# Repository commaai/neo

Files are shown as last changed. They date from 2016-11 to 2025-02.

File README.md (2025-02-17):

neo
=====

<b>NOTE: The NEO is deprecated. Check out the [latest hardware](https://github.com/commaai/hardware).

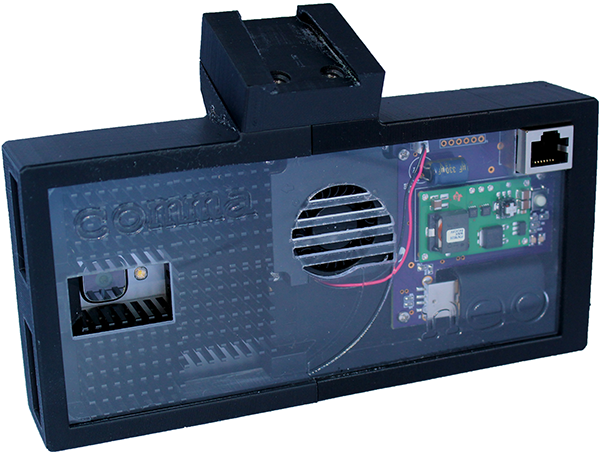
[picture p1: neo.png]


The neo is an open source robotics research platform. It is powered by a OnePlus 3 smartphone and an [STM32F205](http://www.st.com/en/microcontrollers/stm32f2x5.html?querycriteria=productId=LN1433)-based CAN interface board, in a 3d-printed housing with active cooling.

The neo platform includes [NEOS](https://github.com/commaai/eon-neos), a stripped down Android ROM designed for robustness and to get out of the way of your software. It also provides a modern linux environment for easy development.

Why
------

You cannot get a higher performance embedded processor than what's shipping in modern smartphones. They also come with an impressive array of sensors and radios, and are very low cost.

For some background see the work of [Android Based Robots](http://www.socsci.uci.edu/~jkrichma/ABR/abr_background.html).

Build
------

The neo is designed to be very easy to construct. You need to be able to shop online and use a soldering iron.

There is a **[very detailed guide](https://github.com/commaai/neo/raw/master/guide.pdf)** with instructions on what to order and how to build a neo.

to build a neo, 6 orders must be placed from the following sources:
- digikey
- mcmaster
- shapeways
- oshpark
- amazon
- oneplus

The total cost is about $700.

Directory structure
------

- board -- EagleCAD schematic, board, and library files
- parts -- csv bill of materials
- case -- stl files for 3d printing

Licensing
------

neo research platform is released under the MIT license.

**THIS IS ALPHA QUALITY SOFTWARE FOR RESEARCH PURPOSES ONLY. THIS IS NOT A PRODUCT.
YOU ARE RESPONSIBLE FOR COMPLYING WITH LOCAL LAWS AND REGULATIONS.
NO WARRANTY EXPRESSED OR IMPLIED.**

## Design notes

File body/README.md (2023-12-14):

Body
=====

Stands
------

For wheeled stands you can use any office chair wheels but we recommend: <a href="https://www.amazon.com/gp/product/B088D8XHHQ/ref=ppx_yo_dt_b_search_asin_title?ie=UTF8&psc=1">these</a>
They are press-fit so you will need to apply some amount of force (or use wise)

Hat (for C3/C3X)
------

After you print a hat and a hat frame you will also need <a href="https://www.mcmaster.com/93070A107/">4pcs M4x20 screws</a> and <a href="https://www.amazon.com/gp/product/B07T5L7756/ref=ppx_yo_dt_b_search_asin_title?ie=UTF8&th=1">EVA foam</a> to protect the screen of your device. Cut two 9mm x 70mm stripes and apply them to inside of the hat frame.

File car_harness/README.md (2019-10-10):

car harness
===

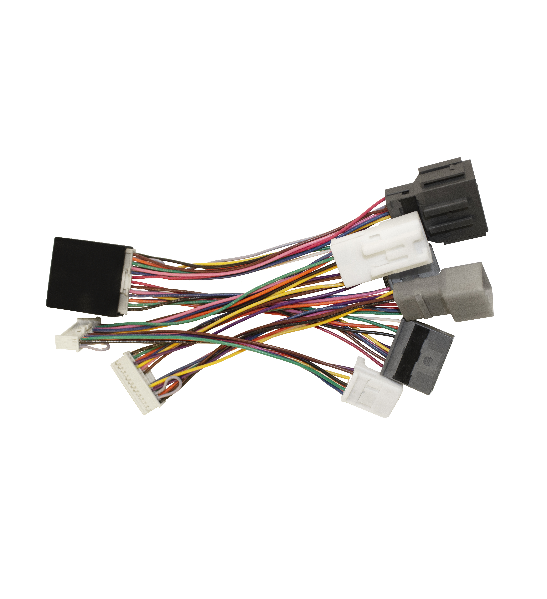
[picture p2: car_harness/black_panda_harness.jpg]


This is the documentation for the 26 pin connector on the car harness.

The car harness currently supports Honda Nidec, Honda Bosch, and Toyota. We would like to support more cars in the future.

Pull requests for additional pin outs are welcome. Please reference the open_pinout.sch.pdf file for adding new cars. This will guarantee the harness will work properly.

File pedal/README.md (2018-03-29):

pedal
=====

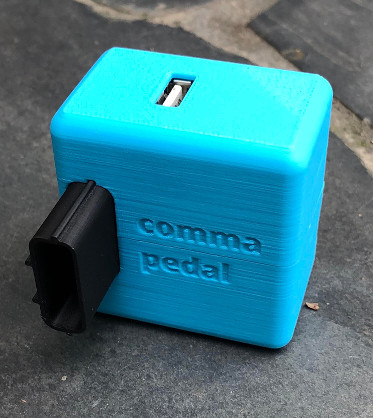
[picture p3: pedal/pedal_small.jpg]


This is the open source hardware for the comma pedal. It borrows from the NEO board.

Open source firmware available at https://github.com/commaai/panda/tree/master/board/pedal

The comma pedal is a gas pedal interceptor for Honda/Acura. It allows you to "virtually" press the pedal, enabling stop and go cruise control on select cars.

Licensing
------

Released under the MIT license.

**THIS IS ALPHA QUALITY HARDWARE FOR RESEARCH PURPOSES ONLY. THIS IS NOT A PRODUCT.
YOU ARE RESPONSIBLE FOR COMPLYING WITH LOCAL LAWS AND REGULATIONS.
NO WARRANTY EXPRESSED OR IMPLIED.**

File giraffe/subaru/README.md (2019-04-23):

Subaru giraffe
====

Get your panda deeper into your Subaru Impreza
May work with other cars with the same connector

====

All switching between stock ADAS on and Stock ADAS off is done via a relay

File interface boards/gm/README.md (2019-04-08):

GM Interface Board

====

Design from the community from: [@vntarasov](https://github.com/vntarasov)

**THIS IS ALPHA QUALITY HARDWARE, NOT TESTED, NOR DESIGNED BY COMMA.AI, FOR RESEARCH PURPOSES ONLY. THIS IS NOT A PRODUCT.
YOU ARE RESPONSIBLE FOR COMPLYING WITH LOCAL LAWS AND REGULATIONS.
NO WARRANTY EXPRESSED OR IMPLIED.**

=====

Parts for case assembly (mcmaster part numbers):
- 92010A122, M3 12mm flat head
- 94180A331, M3 heat insert

PCB parts: digikey.csv

Connector pins:
- For data pins, Digikey part # SAM12735-ND
- For power & ground pins, Mouser part # 829-15304702

Assembly steps:
- Order PCB from Oshpark and populate yourself, or order a populated PCB from Macrofab
  Solder everything except for connector headers and power pins
- Flash the board with
  - Connect 5v, ground, data+, data- to USB host. Use external 5v power
  - Don't use 5v linear regulator for USB power, it will get fried
  - Pull high (to +3.3v net) BOOT testpoint, through 1k resistor, to put board into DFU
- Print case.stl and connector.stl, use ABS filament
- Install m3 heat insert into the case
- Drill holes in the connector housing for easier insertion of data pins, from 0.7mm to 0.75mm
- Cut 0.1" connector header SAM12735-ND to 12-pin and 16-pin sizes
- Cut one of the 829-15304702 short, bend the other one 90 degrees
- Insert shorter 829-15304702 (+12v) into connector housing
  - Put enough solder on the +12v testpoint of the PCB
  - Insert 0.1" headers into PCB, then solder the +12v pin to the PCB
  - Connector's plastic is going to melt, immobilizing the +12v pin is recommended
- Solder 0.1" headers to the PCB
- Insert 90-degrees bent 829-15304702 (ground) into connector housing, solder to PCB
- Bolt down connector housing to the case

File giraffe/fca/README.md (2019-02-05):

FCA (Fiat Chrysler Automotive) Giraffe
====

Get your panda deeper into your:

- 2017 Chrysler Pacifica Hybrid

May fit other FCA cars as well.

The switches
====

The 2 DIP switches control signals to the stock ADAS system

- 1 -- IGN to camera

- 2 -- ADAS CAN1 -> camera CAN (OBDII pins 12 & 13)

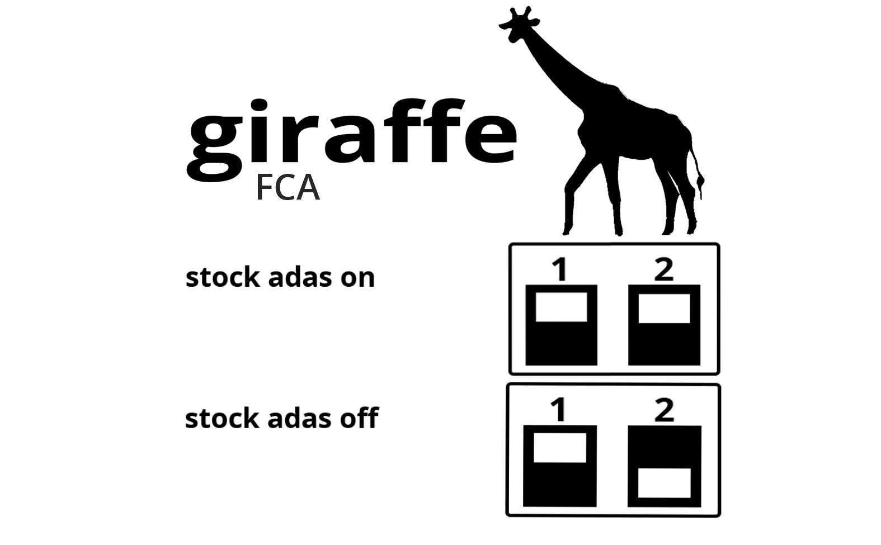
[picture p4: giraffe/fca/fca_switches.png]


Initial design from the community from: [@adhintz](https://github.com/adhintz)

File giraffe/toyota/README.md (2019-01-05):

Toyota giraffe
====

Get your panda deeper into your compatible Toyota vehicle

The switches
====

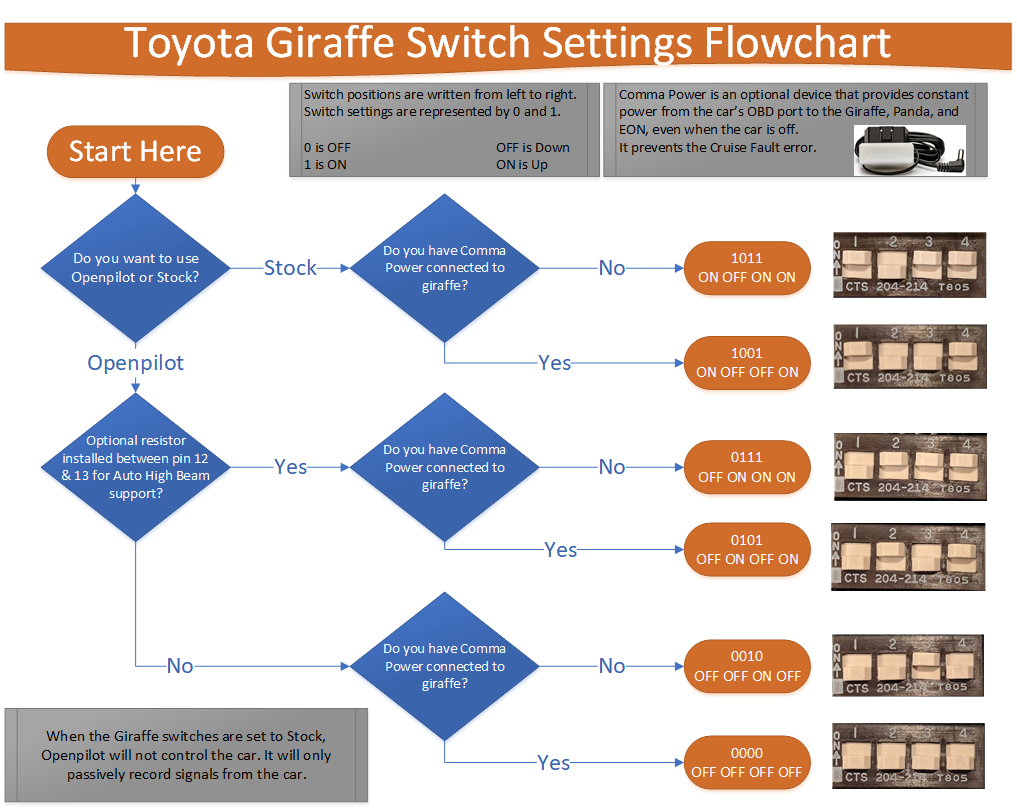
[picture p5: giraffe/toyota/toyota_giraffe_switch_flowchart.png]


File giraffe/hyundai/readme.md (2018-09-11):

Hyundai giraffe
====

Get your panda deeper into your compatible Hyundai vehicle. Built with pinout for our Hyundai Sante Fe. May work with other Hyundai/Kia, check EWD for verification. 

The switches
====

The 4 DIP switches control signals to the stock ADAS system

- 1 -- ADAS CAN1 -> main body CAN

- 2 -- ADAS CAN1 -> panda CAN3 (OBDII pins 12 & 13)

- 3 -- IGNITION POWER -> panda power

- 4 -- ADAS power & ignition -> power & ignition

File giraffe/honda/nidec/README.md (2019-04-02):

Honda giraffe
====

Get your panda deeper into your Honda Civic or Acura ILX

The switches
====

The 4 DIP switches control signals to the stock ADAS system

- 1 -- ADAS CAN1 -> main body CAN

- 2 -- ADAS CAN1 -> panda CAN3 (OBDII pins 12 & 13)

- 3 -- ADAS CAN2 -> radar CAN

- 4 -- ADAS power & ignition -> power & ignition

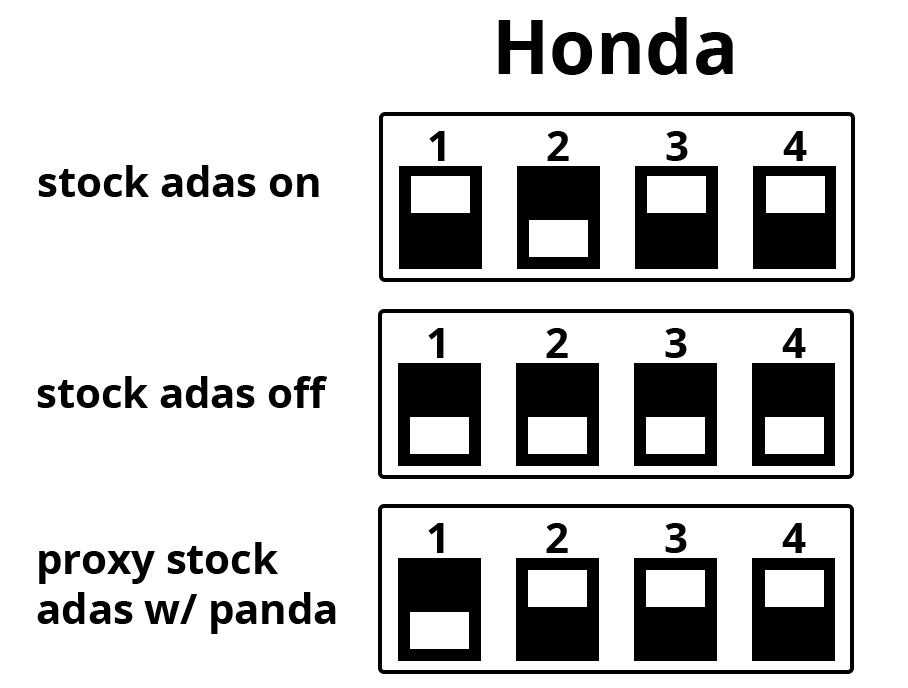
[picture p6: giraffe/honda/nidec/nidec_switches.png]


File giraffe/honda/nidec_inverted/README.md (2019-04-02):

Honda Inverted Giraffe
====

Get your panda deeper into your Odyssey, 2019 Honda Pilot, TLX and probably other cars with an "inverted" connector

The switches
====

The 4 DIP switches control signals to the stock ADAS system

- 1 -- ADAS CAN1 -> main body CAN

- 2 -- ADAS CAN1 -> panda CAN3 (OBDII pins 12 & 13)

- 3 -- ADAS CAN2 -> radar CAN

- 4 -- ADAS power & ignition -> power & ignition



Thanks to [@csouers](https://github.com/csouers) and [@energee](https://github.com/energee) for their input on this design

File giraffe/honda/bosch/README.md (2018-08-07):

Honda giraffe (Bosch ADAS)
====

Get your panda deeper into your:

- 2017+ Honda CR-V
- 2017+ Honda Civic Hatchback
- 2018+ Honda Accord

May fit other Hondas with Bosch hardware as well.

The switches
====

The 2 DIP switches control signals to the stock ADAS system

- 1 -- IGN to camera

- 2 -- ADAS CAN2 -> camera CAN (OBDII pins 12 & 13)

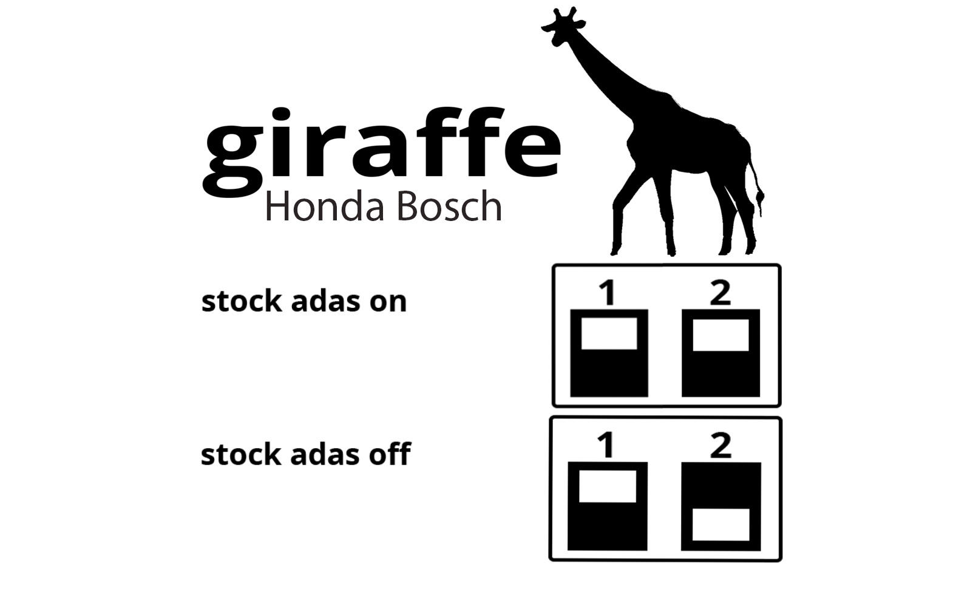
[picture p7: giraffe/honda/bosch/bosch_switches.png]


Initial design from the community from: [@csouers](https://github.com/csouers), [@energee](https://github.com/energee), and Alaric Egli

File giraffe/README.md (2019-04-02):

giraffe
====

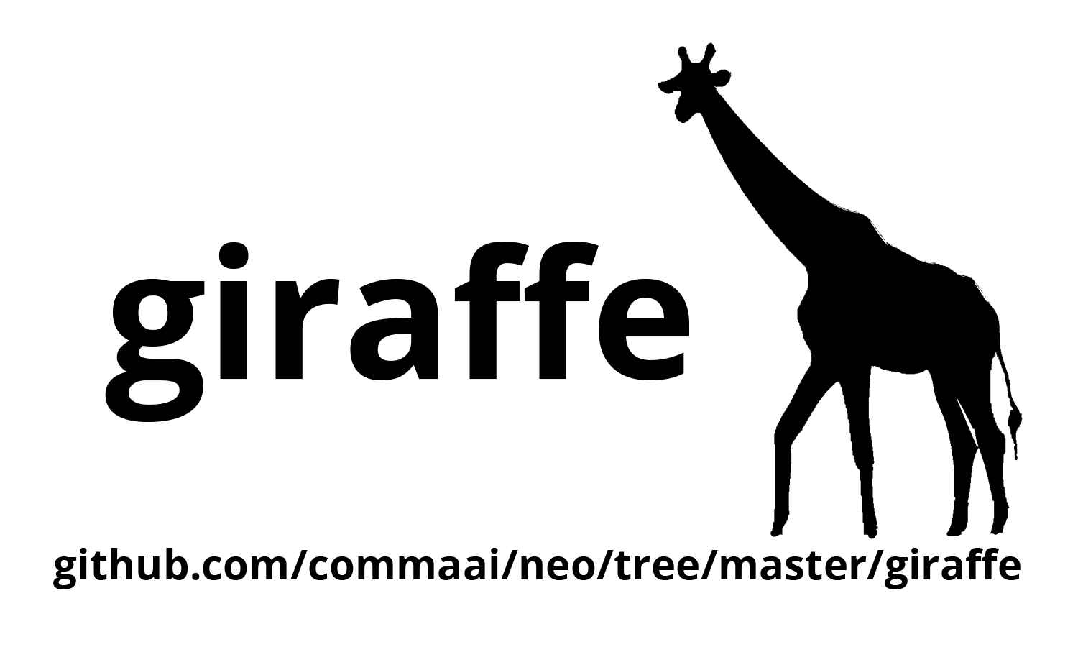
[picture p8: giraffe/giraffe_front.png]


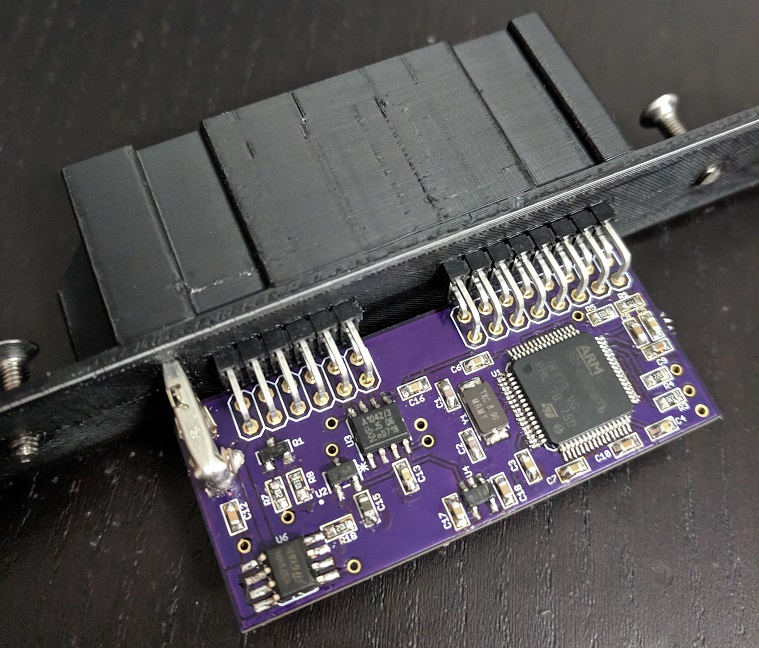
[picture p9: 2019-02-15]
interface boards/gm/resources/1) front.jpg

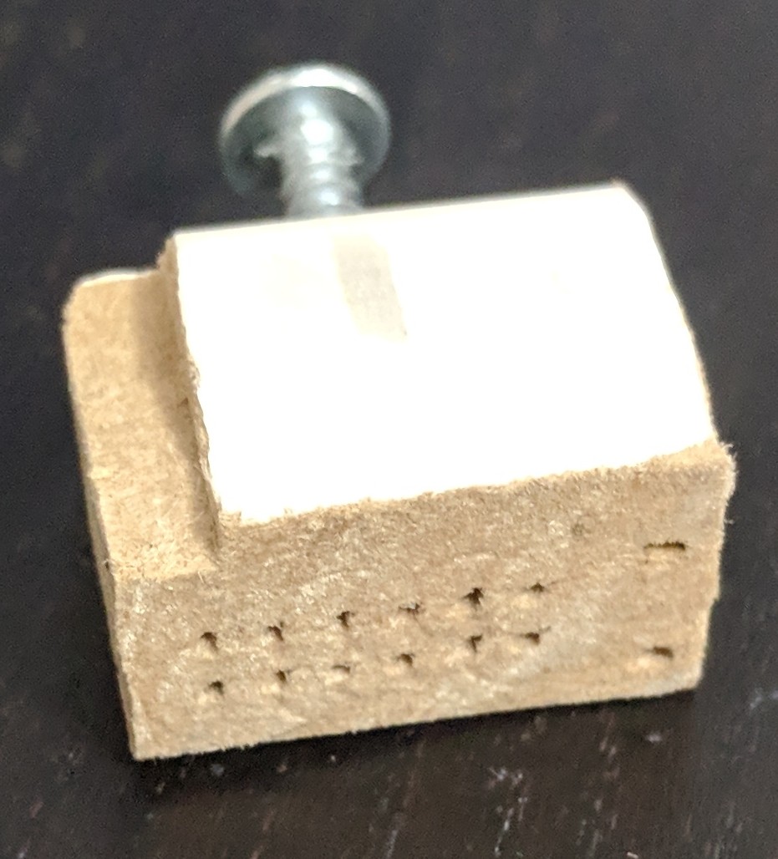
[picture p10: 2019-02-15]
interface boards/gm/resources/4) pin immobilizer.jpg

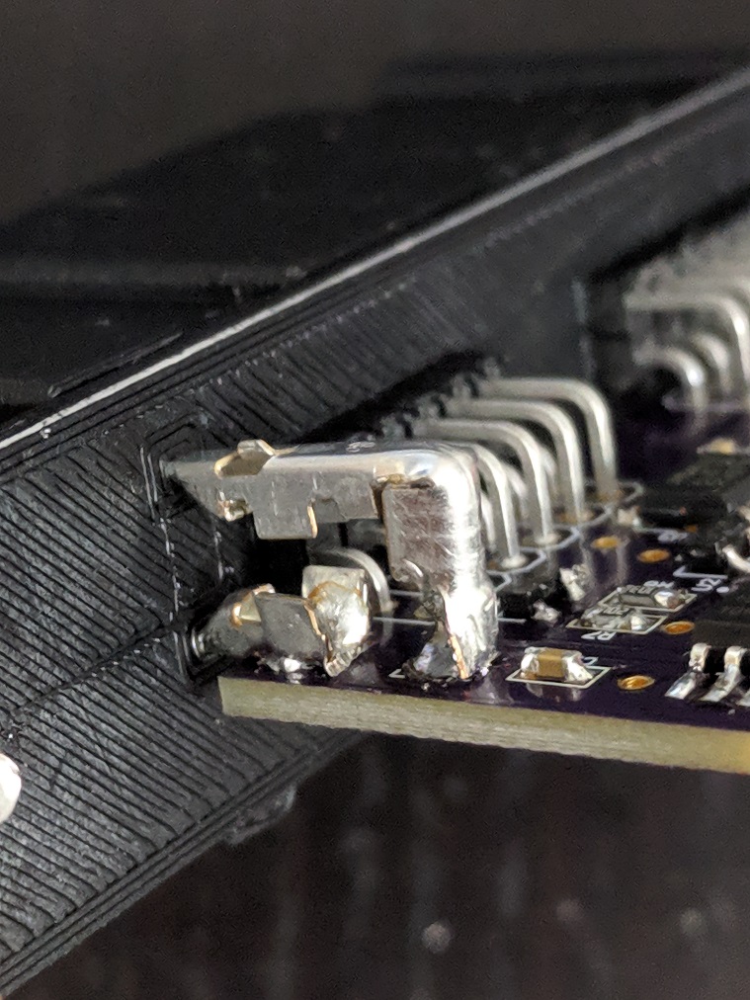
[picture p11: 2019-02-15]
interface boards/gm/resources/2) power pins.jpg

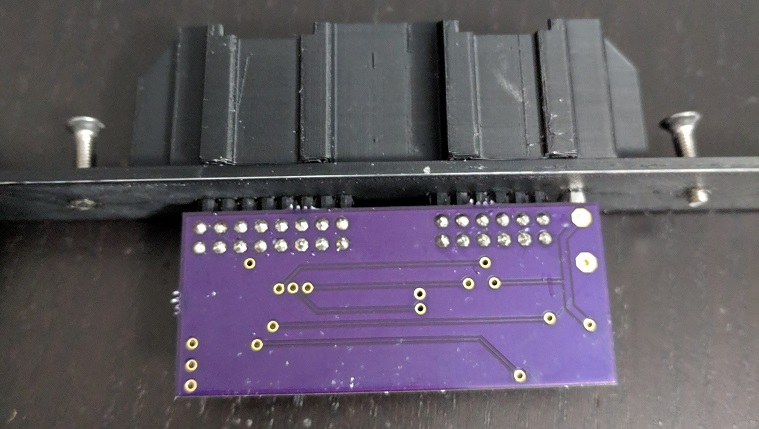
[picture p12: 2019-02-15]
interface boards/gm/resources/3) back.jpg

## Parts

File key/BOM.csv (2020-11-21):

Part | Value | Device | Package | Description | DESIGNER | MPN | POPULARITY | VERSION
DFU | SPST-2-4PIN | SPST-2-4PIN | EVQ-Q2 |  |  | EVQ-Q2Y03W
J1 | USB-C | USB-C | USB-C |  |  | 10544440001
J2 | USB-C-FEMALE | USB-C-FEMALE | DX07S024XJ1R1100 |  |  | DX07S024XJ1R1100
SHIELD |  | 1,6/0,8 | 1,6/0,8 | THROUGH-HOLE PAD |  |  | 15
SW2 | DPDTDPDT | DPDTDPDT | AYZ0202 |  |  | JS202011SCQN

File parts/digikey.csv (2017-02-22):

digikey part num | order qty | qty used | ref des | value | footprint
1276-1817-1-ND | 3 | 2 | C1, C2 | 8pF | 0603
490-1532-1-ND | 10 | 9 | C3, C4, C5, C6, C7, C11, C13, C16, C17 | 100nF | 0603
490-3296-1-ND | 4 | 3 | C9, C10, C18 | 2.2uF | 0603
490-10744-1-ND | 3 | 2 | C12, C15 | 2.2uF | 0805
P12372-ND | 1 | 1 | C14 | 330uF | radial
1276-1784-1-ND | 2 | 1 | C8 | 4.7uF | 0603
S1011EC-40-ND | 1 | 1 | J1 | uart connector | thru hole-6
WM1731-ND | 1 | 1 | J2 | fan connector | thru hole-2
WM17118-ND | 1 | 1 | J3 | usb a | smd-4
AE10398-ND | 1 | 1 | J4 | rj45 | thru hole-8
670-2294-ND | 1 | 1 | J5 | jae 20 pin | thru hole-20
475-1410-1-ND | 2 | 1 | LED1 | green | 0805
475-1415-1-ND | 2 | 1 | LED2 | red | 0805
MMBT2222ALT1GOSCT-ND | 2 | 1 | Q1 | mmbt2222a | sot23-3
311-10KGRCT-ND | 10 | 6 | R1, R5, R8, R12, R14, R15 | 10k | 0603
311-18.7KHRCT-ND | 10 | 1 | R11 | 18.7k | 0603
311-1.0KGRCT-ND | 10 | 2 | R6, R7 | 1k | 0603
311-2.7KGRCT-ND | 10 | 2 | R2, R13 | 2.7k | 0603
311-22GRCT-ND | 10 | 2 | R3, R4 | 22 | 0603
311-220GRCT-ND | 10 | 2 | R9, R10 | 220 | 0603
P12961SCT-ND | 1 | 1 | SW1 | spst | smd-4
497-11153-ND | 1 | 1 | U1 | stm32f205 | lqfp-64
296-20515-ND | 1 | 1 | U2 | ptn78020w | thru hole-7
568-8681-1-ND | 1 | 1 | U3 | tja1048 | so14
296-36844-1-ND | 2 | 1 | U4 | 3.3v | sot23-5
887-1667-1-ND | 2 | 1 | Y1 | 8MHz | smd-2
603-1840-ND | 1 | 1 | H1 | 12V fan | 40x10mm
345-1102-ND | 4 | 4 | H2, H3, H4, H5 | heatsink | 28mm

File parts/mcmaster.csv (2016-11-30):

mcmaster part num | pack qty | qty used | ref des | description
92010A005 | 1 | 1 | A | m2 10mm flat head
92010A122 | 1 | 4 | B | m3 12mm flat head
92000A013 | 1 | 7 | C | m2 6mm pan head
91828A111 | 1 | 6 | D | m2 hex nut
94180A331 | 1 | 4 | E | m3 heat set insert
94180A307 | 1 | 2 | F | m2 heat set insert

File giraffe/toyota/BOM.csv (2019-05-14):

Ref Des | Package | Manufacturer PN | Qty | Link
J1 | 12-pin | 1318774-1 | 1 | http://www.mouser.com/Search/ProductDetail.aspx?R=1318774-1virtualkey57100000virtualkey571-1318774-1
J2 | 12-pin-RA | 1318772-2 | 1 | http://www.mouser.com/Search/ProductDetail.aspx?R=1318772-2virtualkey57100000virtualkey571-1318772-2
 |  | 1123343-1 | 12 | https://www.digikey.com/product-detail/en/te-connectivity-amp-connectors/1123343-1/A107011CT-ND/3488572
 |  | PRPC040SAAN-RC | 1 | https://www.digikey.com/products/en?keywords=S1011EC-40-ND
J3 | 16-pin | OBDII-FEMALE | 1 | https://cn1514770021qfbj.en.alibaba.com/product/60598699808-804284542/J1962F_OBD2_16_Pin_Female_connector_OBD2_Socket.html
J4 | RJ45-RA | A-2004-2-4-LPS-N-R | 1 | https://www.digikey.com/product-detail/en/assmann-wsw-components/A-2004-2-4-LPS-N-R/AE10387-ND/2183638
J5 | 3-pin | EJ508A | 1 | https://www.digikey.com/products/en?keywords=ej508a
SW1 | SMD | 204-214ST | 1 | https://www.digikey.com/scripts/DkSearch/dksus.dll?Detail&itemSeq=238874105&uq=636415194298612120
R1 | 0603 | ERJ-PA3F1200V | 1 | https://www.digikey.com/short/p47rhj
SCREWs | Phillips | 92010A118 | 2 | https://www.mcmaster.com/#catalog/92010A118

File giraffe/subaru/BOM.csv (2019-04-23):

Comma Access Point
Ref Des | Package | Manufacture PN | Qty | Link
J1 | 26 Pin R/A | 5018762640 | 1 | https://www.digikey.com/product-detail/en/molex/501876-2640/WM6091-ND/1787792
J2 | 10 Pin R/A | 5018761040 | 1 | https://www.digikey.com/products/en?keywords=501876-1040
J3 | 2 Pin R/A | 3-794618-2 | 1 | https://www.digikey.com/product-detail/en/te-connectivity-amp-connectors/3-794618-2/A33252-ND/1114990
R1 | DNP | DNP | DNP
R2 | R0402 | ERJ-2GEJ121X | 1 | https://www.digikey.com/product-detail/en/panasonic-electronic-components/ERJ-2GEJ121X/P120JCT-ND/146744
R4 | R0402 | ERJ-2GE0R00X | 1 | https://www.digikey.com/product-detail/en/panasonic-electronic-components/ERJ-2GEJ121X/P120JCT-ND/146744
C1 | DNP | DNP | DNP
S1 |  | G6S-2G DC12 | 1 | https://www.digikey.com/product-detail/en/omron-electronics-inc-emc-div/G6S-2G-DC12/Z892-ND/20450
D1,D2 | SMD | ES2BA-13-F | 1 | https://www.digikey.com/product-detail/en/diodes-incorporated/ES2BA-13-F/ES2BA-FDICT-ND/815690
Panda Interface Point
Ref Des | Package | Manufacture PN | Qty | Link
J1 | OBDII |  | 1 | https://cn1514770021qfbj.en.alibaba.com/product/60598699808-804284542/J1962F_OBD2_16_Pin_Female_connector_OBD2_Socket.html
J2 | RJ45 R/A | A-2004-2-4-LPS-N-R | 1 | https://www.digikey.com/product-detail/en/assmann-wsw-components/A-2004-2-4-LPS-N-R/AE10387-ND/2183638
J3 | 10 Pin R/A | 5018761040 | 1 | https://www.digikey.com/products/en?keywords=501876-1040
Wiring Harness
Ref Des | Package | Manufacture PN | Qty | Link
 | 10 Pin Female | 5016461000 | 2 | https://www.digikey.com/product-detail/en/molex/5016461000/WM6058-ND/1787759
 | 26 Pin Female | 5016462600 | 1 | https://www.digikey.com/short/ppwt0m
 | Molex Crimp Pins | 5016471000 | 44 | https://www.digikey.com/product-detail/en/molex/5016471000/WM6057CT-ND/1787797
 | 16 Pin Male | 1565476-1 | 1 | https://www.mouser.com/ProductDetail/TE-Connectivity/1565476-1
 | 16 Pin Female | 1318386-1 | 1 | https://www.digikey.com/product-detail/en/te-connectivity-amp-connectors/1318386-1/A106550-ND/2273493
 | TE Connectivity crimp pins | 1123343-1 | 24 | https://www.digikey.com/product-detail/en/te-connectivity-amp-connectors/1123343-1/A107011CT-ND/3488572

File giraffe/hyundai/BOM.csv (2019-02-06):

Ref Des | Package | Manufacturer PN | Qty | Link
U1 | 12-Pin | MG645845 | 1 | https://chcwld.en.alibaba.com/product/60784996669-801836231/KET_020_12M_Automotive_cable_connector_Electronic_Connector.html
U2 | 12-Pin | MG655794 | 1 | https://chcwld.en.alibaba.com/product/60784830234-801836231/KET_020_12F_Automotive_cable_connector_Electronic_Connector.html
 |  | ST731407-3 | 12
J1 | 16-pin | OBDII-FEMALE | 1 | https://cn1514770021qfbj.en.alibaba.com/product/60598699808-804284542/J1962F_OBD2_16_Pin_Female_connector_OBD2_Socket.html
J2 | RJ45-RA | A-2004-2-4-LPS-N-R | 1 | https://www.digikey.com/product-detail/en/assmann-wsw-components/A-2004-2-4-LPS-N-R/AE10387-ND/2183638
J3 | 3-pin | EJ508A | 1 | https://www.digikey.com/products/en?keywords=ej508a
SW1 | SMD | 204-214ST | 1 | https://www.digikey.com/scripts/DkSearch/dksus.dll?Detail&itemSeq=238874105&uq=636415194298612120
R1 | 0603-R | ERJ-PA3J121V | 1 | https://www.digikey.com/product-detail/en/panasonic-electronic-components/ERJ-PA3J121V/P120BZCT-ND/5036246

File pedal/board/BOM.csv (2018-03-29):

Ref Des | Value | Package | Qty | MPN | Link
C1, C2, C16 | 2.2uF | 0603-C | 3 | EMK107BJ225KA-T
C12 | 4.7uF | 0603-C | 1 | CL10A475KQ8NNNC
C3, C4 | 12pF | 0603-C | 2 | C1608C0G1H120J080AA
C5, C6, C8, C9, C10, C11, C13, C15, C26 | 100nF | 0603-C | 9 | GCM188R71C104KA37D
J1, J2 | - | 1X06_NO_SILK_YES_STOP | 2 | -
J15 | RJ45 | RA-RJ45 | 1 | A-2004-2-4-LPS-N-R
J3 | USB-ASMD-F | USB-A-S | 1 | 87583-2010BLF
J4 | HONDA-6PIN |  | 1 | HONDA-6PIN | https://www.aliexpress.com/item/Female-Male-6-Pin-Electrical-Accelerator-Pedal-Sensor-Connector-Auto-Plug-For-Honda-Acura-Nissan-7287/32829238822.html
LED1 | GREEN | CHIPLED_0805 | 1 | LG R971-KN-1
R1, R2, R3, R4, R7, R8 | 10k, 0.1% | 0402-R | 6 | ERA-2AEB103X
R13 | 220 | 0402-R | 1 | RC0402FR-07220RL
R16, R17 | 22 | 0402-R | 2 | RC0402FR-0722RL
R23, R24, R25, R26 | 1k, 0.1% | 0402-R | 4 | ERA-2AEB102X
R5, R6 | 10k | 0402-R | 2 | RC0402JR-0710KL
U1 | STM32-M-64-LQFP | LQFP64 | 1 | STM32F205RET6
U2 | 3V3 | SOT23-5 | 1 | TPS73433TDDCRQ1
U3 | TJA1042HVSON | HVSON8 | 1 | TJA1042TK/3/1J
U6 | MCP6002 | SO08 | 1 | MCP6002T-I/SN
Y1 | 16MHz | XTAL-3.2X2.5 | 1 | ABM8AIG-16.000MHZ-12-2Z-T3

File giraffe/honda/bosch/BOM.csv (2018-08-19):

Ref Des | Package | MPN | Qty | Link
J3 | 12-pin | OBDII-FEMALE | 1 | https://www.alibaba.com/product-detail/J1962F-OBD2-OBD-2-16-Pin_60657250485.html
SW1 | SMD | CT204212ST-ND | 1 | https://www.digikey.com/products/en?mpart=204-212ST&v=119
J1 | 3-pin | EJ508A-ND | 1 | https://www.digikey.com/products/en?keywords=ej508a
J4 | RJ45-VERT | AE10399-ND | 1 | https://www.digikey.com/scripts/DkSearch/dksus.dll?Detail&itemSeq=265472924&uq=636662223909317983
J5 | 12 Pin | M34S75C4F1 | 12 | https://www.digikey.com/product-detail/en/jae-electronics/M34S75C4F1/670-2268-2-ND/2044176
J2 | 12 Pin | S1211EC-40-ND | 12 | https://www.digikey.com/product-detail/en/sullins-connector-solutions/PRPC040SFAN-RC/S1211EC-40-ND/2775334
D1 | SMD | ES2BA-13-F | 1 | https://www.digikey.com/product-detail/en/diodes-incorporated/ES2BA-13-F/ES2BA-FDICT-ND/815690
M3 8mm | Hex | 91294A132 | 1 | https://www.mcmaster.com/#91294A128
M3 14 mm | Hex | 91294A128 | 2 | https://www.mcmaster.com/#91294A133
Nut | Hex | 91828A211 | 2 | https://www.mcmaster.com/#catalog/124/3276/=1doa85x

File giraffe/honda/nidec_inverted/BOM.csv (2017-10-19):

Ref Des | Package | Manufacturer PN | Qty | Link
J1 | 20-pin-RA | MX34020NF1 | 1 | https://www.digikey.com/product-detail/en/jae-electronics/MX34020NF1/670-2924-ND/2139260
J2 | 20-pin | MX34020SF1 | 1 | https://www.digikey.com/scripts/DkSearch/dksus.dll?Detail&itemSeq=238973409&uq=636415194298622122
 |  | M34S75C4F1 | 20 | https://www.digikey.com/product-detail/en/jae-electronics/M34S75C4F1/670-2268-1-ND/2044290
 |  | PRPC040SAAN-RC | 1 | https://www.digikey.com/products/en?keywords=S1011EC-40-ND
J3 | 16-pin | OBDII-FEMALE | 1 | https://cn1514770021qfbj.en.alibaba.com/product/60598699808-804284542/J1962F_OBD2_16_Pin_Female_connector_OBD2_Socket.html
J4 | RJ45-VERT | A-2014-2-4-LP/FS-R | 1 | https://www.digikey.com/scripts/DkSearch/dksus.dll?Detail&itemSeq=238773681&uq=636415194298592116
SW1 | SMD | 204-214ST | 1 | https://www.digikey.com/scripts/DkSearch/dksus.dll?Detail&itemSeq=238874105&uq=636415194298612120
SCREWs | Phillips | 92010A118 | 2 | https://www.mcmaster.com/#catalog/92010A118

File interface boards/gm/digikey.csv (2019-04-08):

digikey part num | order qty | qty used | ref des | value | footprint
497-15994-1-ND | 1 | 1 | U6 | VN7140 | SO08
568-8678-1-ND | 1 | 1 | U3 | tja1042 | SO-8-L
MCP1703T-5002E/CBCT-ND | 1 | 1 | U2 | 5v | SOT-23A
1727-2160-1-ND | 1 | 1 | Q1 | 0.1A | SOT-23-3
296-36844-1-ND | 1 | 1 | U4 | 3.3v | SOT-23-5
P120DBCT-ND | 1 | 1 | R1 | 120 | 0603
497-11153-ND | 1 | 1 | U1 | stm32f205 | lqfp-64
490-10731-1-ND | 5 | 4 | C9, C10, C12, C18 | 2.2uF | 0603
1276-1900-1-ND | 3 | 2 | C8, C15 | 4.7uF | 0603
887-1667-1-ND | 1 | 1 | Y1 | 8MHz | smd-2
1276-1012-1-ND | 10 | 8 | C3, C4, C5, C6, C7, C13, C16, C17 | 100nF | 0603
311-22GRCT-ND | 10 | 2 | R3, R4 | 22 | 0603
1276-1817-1-ND | 3 | 2 | C1, C2 | 8pF | 0603
311-1.0KGRCT-ND | 10 | 2 | R7, R18 | 1k | 0603
311-10KGRCT-ND | 10 | 2 | R5, R8 | 10k | 0603

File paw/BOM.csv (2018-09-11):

Ref Des | Package | Value | Manufacturer PN | Qty
S3 | DPDT | DPDTDPDT | JS202011SCQN | 1
SW1 | SPST_TACT-EVQQ2 | SPST_TACT-EVQQ2 | EVQ-Q2Y03W | 1
X1 | USB-AA-M | USB-AA-M | 1001-011-01101 | 1
J2 | USB-MINIBSMD | USB-MINIBSMD | 10033526-N3212LF | 1

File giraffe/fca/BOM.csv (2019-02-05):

Ref Des | Package | MPN | Qty | Link
J1 | 3-pin | RASM722PX | 1 | https://www.digikey.com/products/en?keywords=RASM722PX
J2 | OBDII | J1962F | 1 | https://www.alibaba.com/product-detail/J1962F-OBD2-OBD-2-16-Pin_60657250485.html
J3 | RJ45-RA | A-2004-2-4-LPS-N-R | 1 | https://www.digikey.com/product-detail/en/assmann-wsw-components/A-2004-2-4-LPS-N-R/AE10387-ND/2183638
J4 | CONN HEADER VERT | 348250124 | 1 | https://www.digikey.com/product-detail/en/0348250124/WM10326-ND/4504599/?itemSeq=281019679
J5 | MINI50 CONN RCPT | 348240124 | 1 | https://www.digikey.com/product-detail/en/molex-llc/0348240124/WM10324-ND/4504597
SW1 | SMD | CT204212ST-ND | 1 | https://www.digikey.com/products/en?mpart=204-212ST&v=119
D1 | SMD | ES2BA-13-F | 1 | https://www.digikey.com/product-detail/en/diodes-incorporated/ES2BA-13-F/ES2BA-FDICT-ND/815690
R1 | 0603R | ERJ-PA3J121V | 1 | https://www.digikey.com/product-detail/en/panasonic-electronic-components/ERJ-PA3J121V/P120BZCT-ND/5036246
Crimps |  | 5600230421 | 12 | https://www.digikey.com/product-detail/en/molex-llc/5600230421/WM8745CT-ND/3178491
Pins | S1011EC-40-ND |  | 12 | https://www.digikey.com/products/en?keywords=S1011EC-40-ND

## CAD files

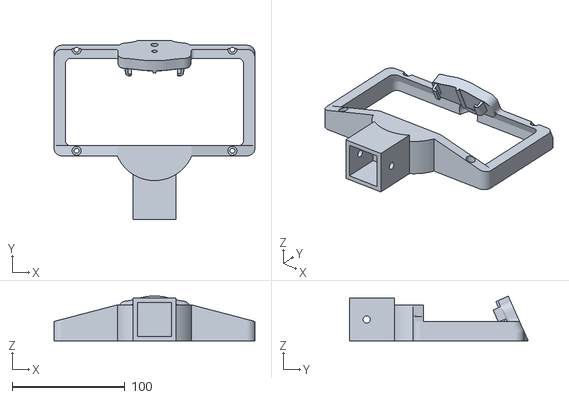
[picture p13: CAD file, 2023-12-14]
body/universal_C3_C3X_hat.stl
178.0 x 158.1 x 39.7

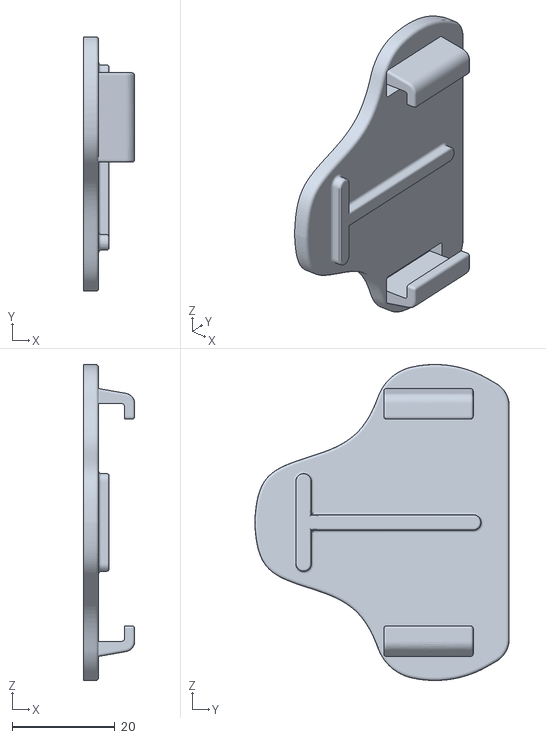
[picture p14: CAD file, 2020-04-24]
case/comma2/comma2_injection_molded_mount.stl
10.0 x 49.5 x 61.5

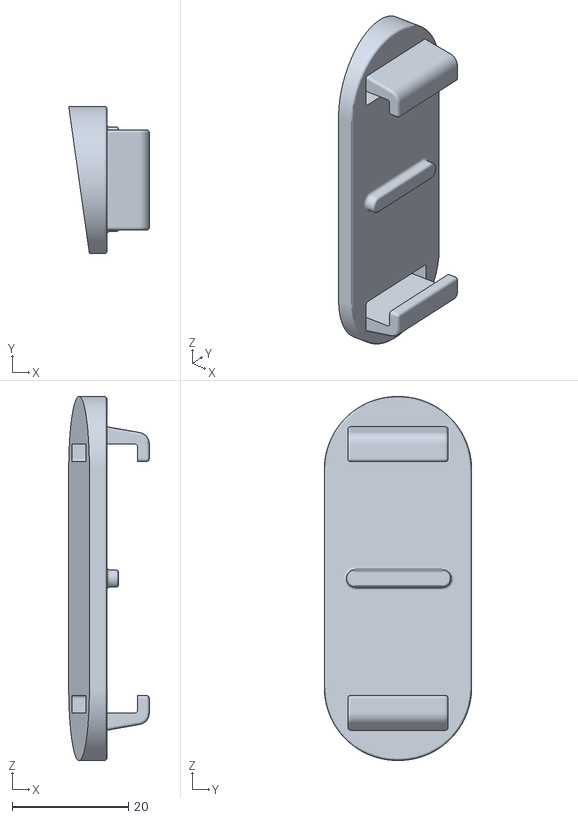
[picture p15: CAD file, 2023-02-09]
case/comma3/8_degree_c3_mount.stl
13.9 x 25.4 x 62.6

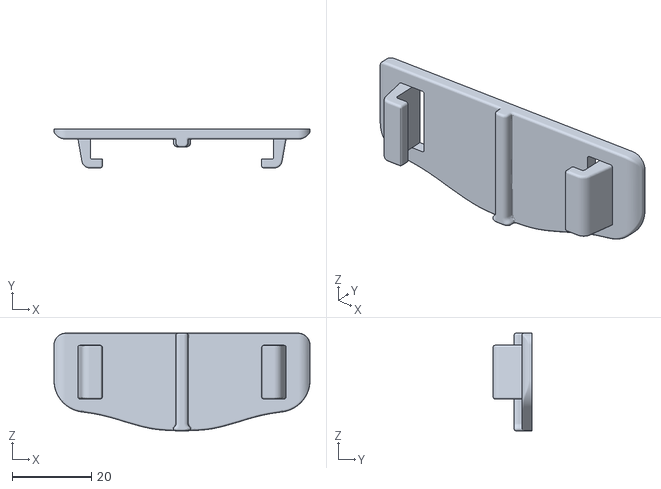
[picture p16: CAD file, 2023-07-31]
case/comma3X/3X_mount.stl
64.6 x 9.80 x 24.6

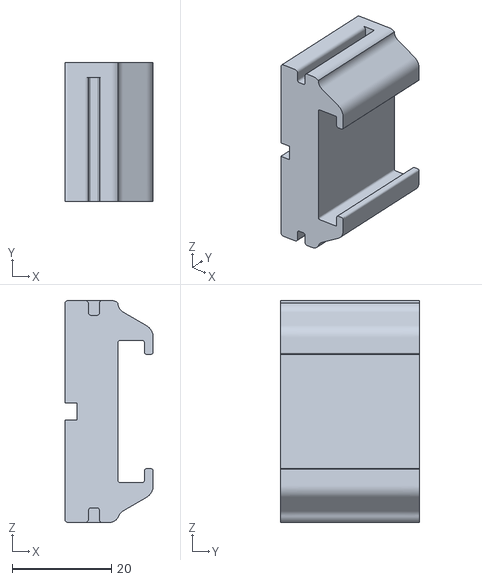
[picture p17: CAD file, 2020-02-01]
case/eon/mount_adapter.stl
17.9 x 28.0 x 44.8

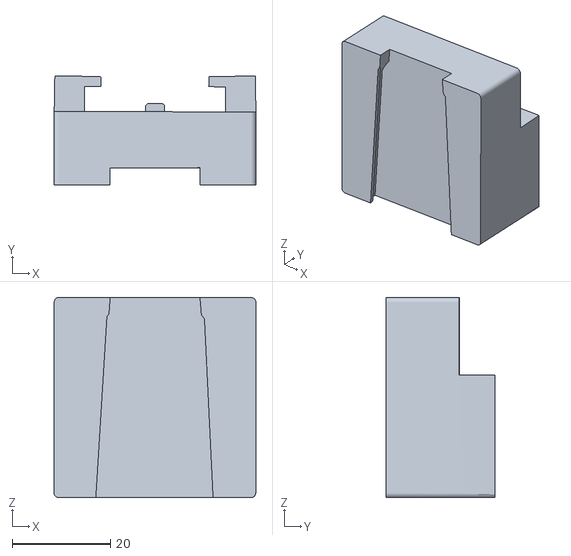
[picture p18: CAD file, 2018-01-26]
case/honda_mirror_togopro.stl
41.2 x 22.3 x 40.8

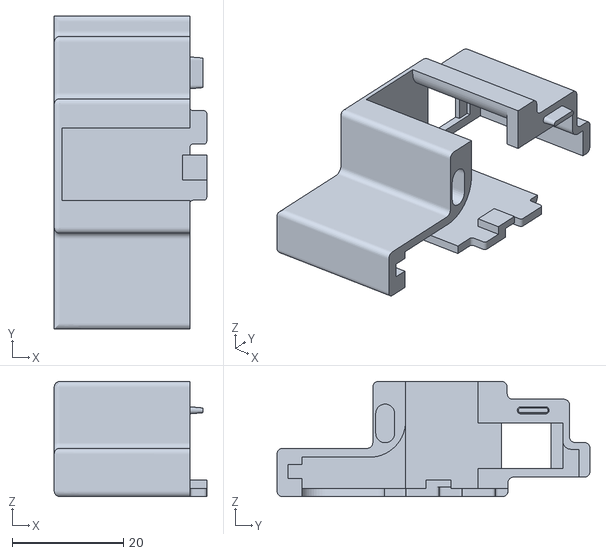
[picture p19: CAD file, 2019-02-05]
giraffe/fca/Giraffe_left.stl
27.4 x 56.2 x 20.7

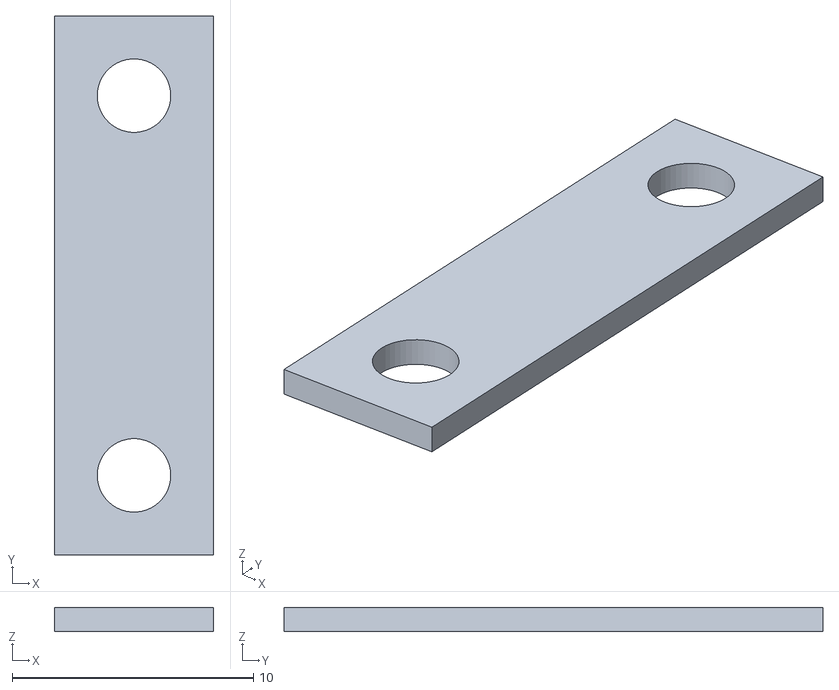
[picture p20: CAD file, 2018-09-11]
giraffe/ford/mechanical/giraffe_ford_spacer.stl
6.60 x 22.4 x 1.00

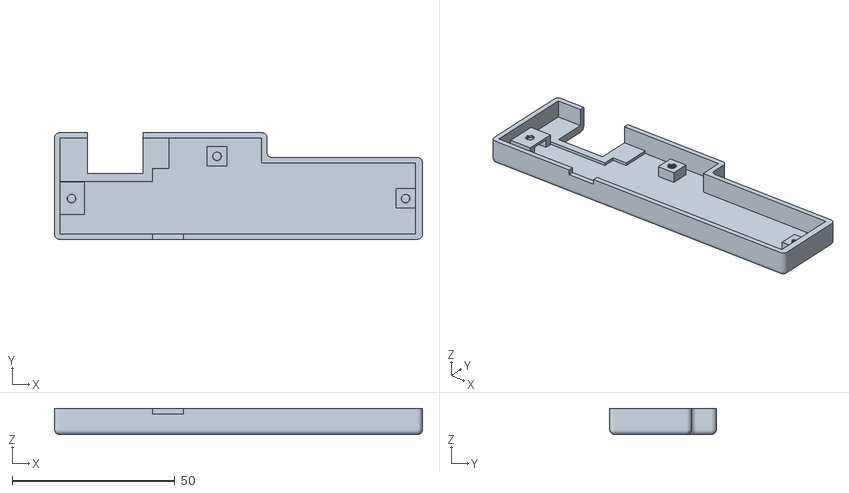
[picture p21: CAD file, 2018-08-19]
giraffe/honda/bosch/bosch_back.stl
113.0 x 32.7 x 8.00

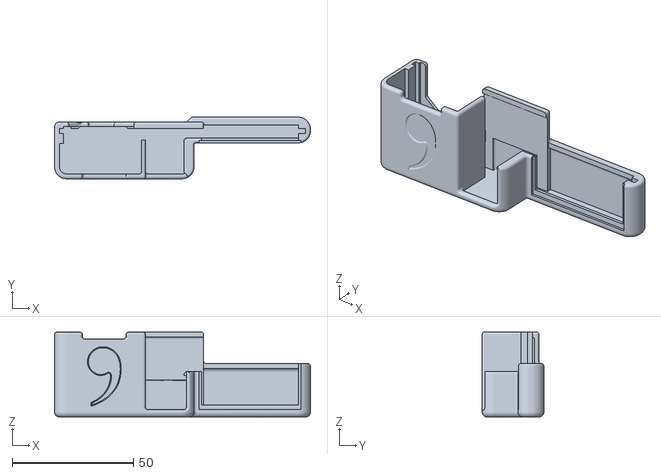
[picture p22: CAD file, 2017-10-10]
giraffe/honda/nidec/case.stl
105.5 x 25.4 x 35.0

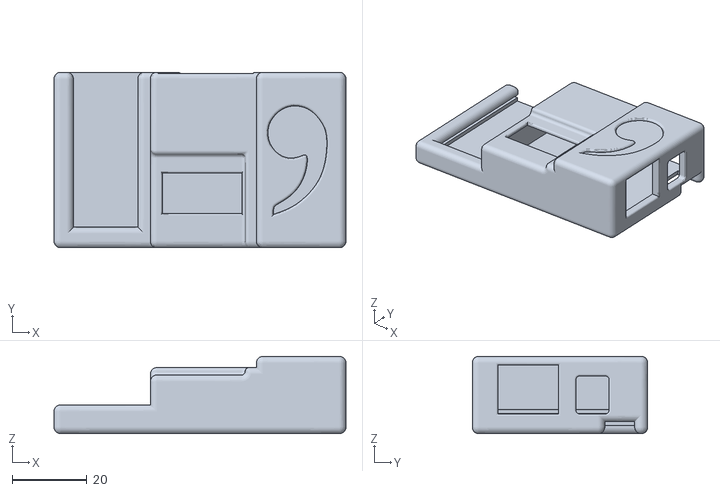
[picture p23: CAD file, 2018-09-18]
giraffe/hyundai/Hyundai_Giraffe.stl
78.2 x 47.0 x 20.7

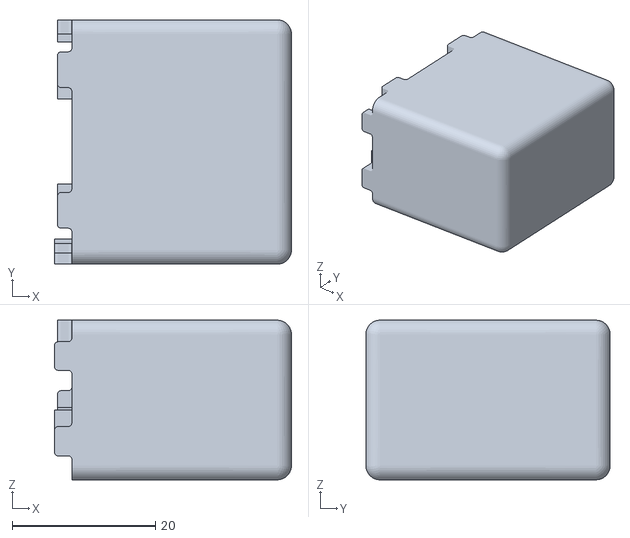
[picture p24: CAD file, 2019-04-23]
giraffe/subaru/PIP_right.stl
33.1 x 34.1 x 22.3

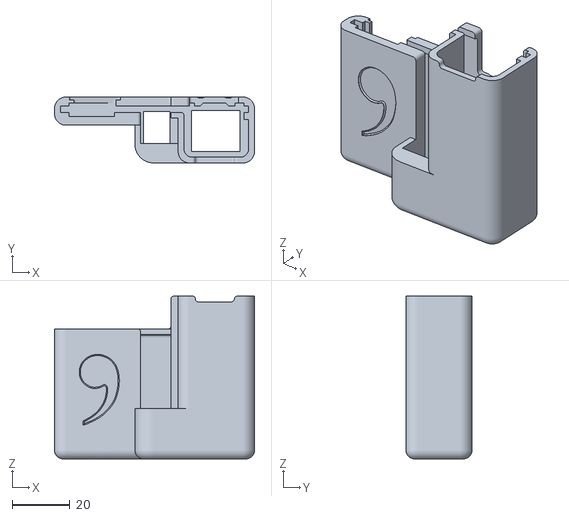
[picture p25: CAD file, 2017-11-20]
giraffe/toyota/case.stl
69.4 x 22.9 x 56.5

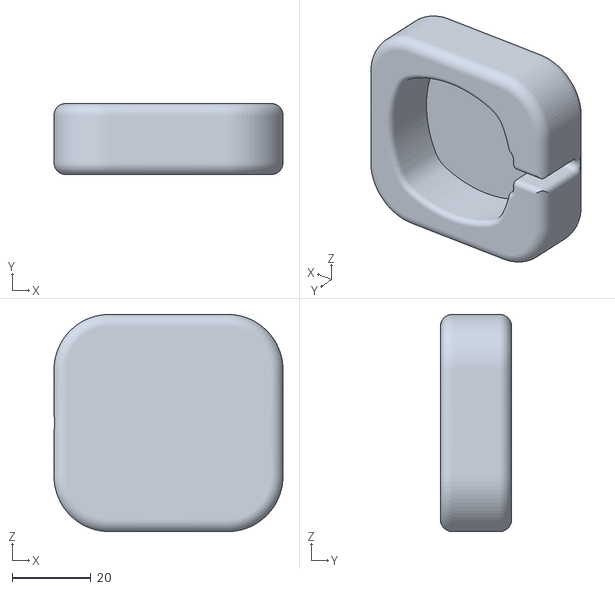
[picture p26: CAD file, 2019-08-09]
grey/flat_antenna_mount.stl
58.0 x 18.0 x 55.0

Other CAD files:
giraffe/honda/nidec_inverted/case.stl
interface boards/gm/case.stl
pedal/case/pedal_connector.stl
body/universal_C3_C3X_hat_frame.stl
body/C3_stand.stl
body/wheeled_stand.stl
car_harness/v1/connectors/Ford_Q4_connector.stl
car_harness/v1/connectors/Ford_Q4_connector_cap.stl
car_harness/v1/connectors/RAM_connector.stl
car_harness/v1/connectors/RAM_connector_cap.stl
case/bottom.stl
case/comma2/comma2_mount.stl
case/comma3/comma3_mount.stl
case/comma3X/3X_mount_8deg.stl
case/cover.stl
case/eon/22deg.stl
case/eon/24deg.stl
case/eon/26deg.stl
case/eon/28deg.stl
case/eon/30deg.stl
case/goproslide.stl
case/mount.stl
case/top.stl
giraffe/fca/Giraffe_right.stl
giraffe/ford/mechanical/giraffe_ford_bottom.stl
giraffe/ford/mechanical/giraffe_ford_top.stl
giraffe/honda/bosch/bosch_female_connector.stl
giraffe/honda/bosch/bosch_front.stl
giraffe/honda/bosch/bosch_male.stl
giraffe/subaru/PIP_left.stl
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

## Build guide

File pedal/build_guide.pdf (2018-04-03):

## comma pedal build guide

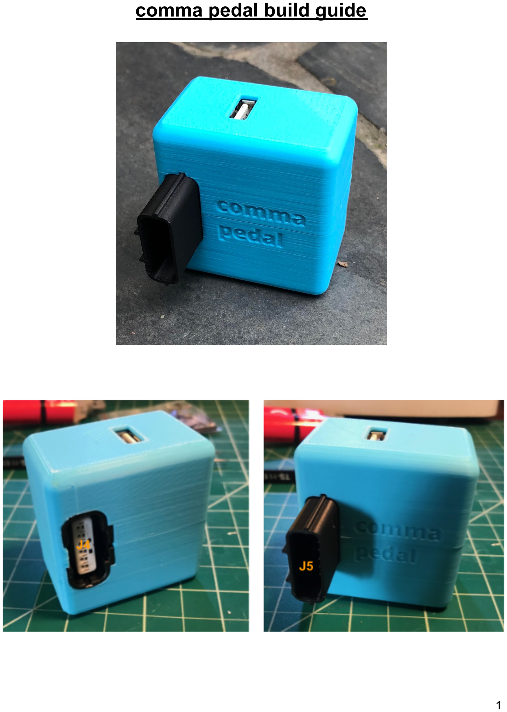
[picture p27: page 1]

1. Cut the tab off of J4. Snip on the red line.

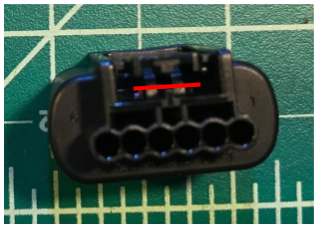
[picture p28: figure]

2. Cut ~3.5” of cable to use on the pins of J4. IDE cable is recommended.
3. Strip, tin, and solder the wires to the J4 pins that come with the plastic housing from Aliexpress (sockets)

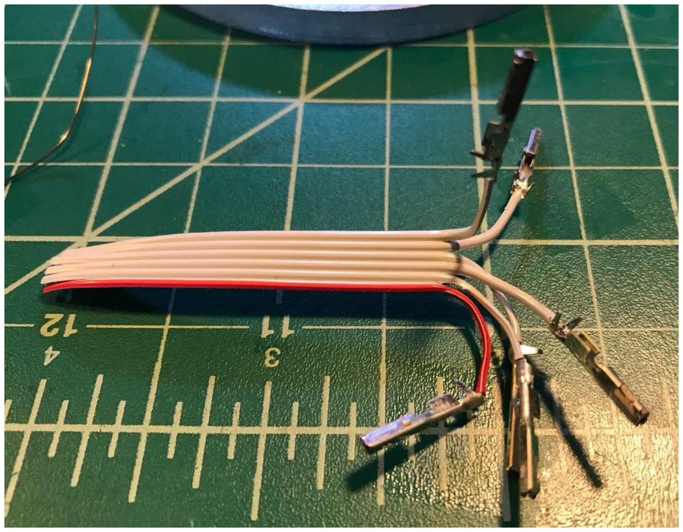
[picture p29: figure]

4. Use a pair of needle nose pliers to crimp down the flanges on the J4 connectors

5. Insert the pins into J4

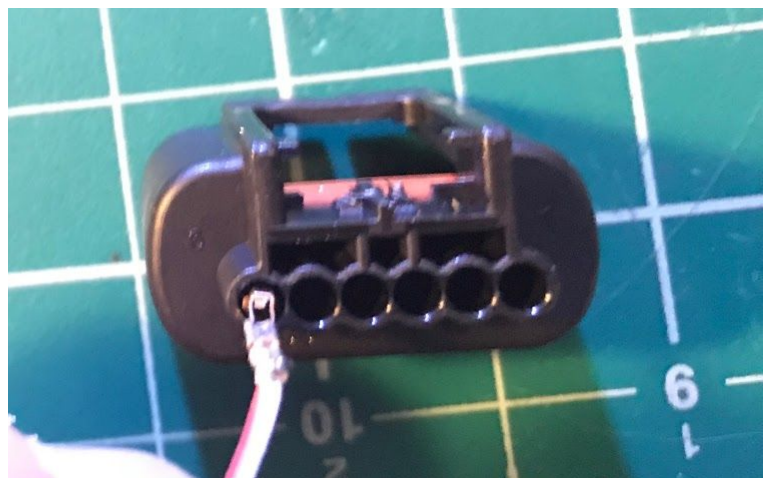
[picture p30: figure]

6. They should look like this when done

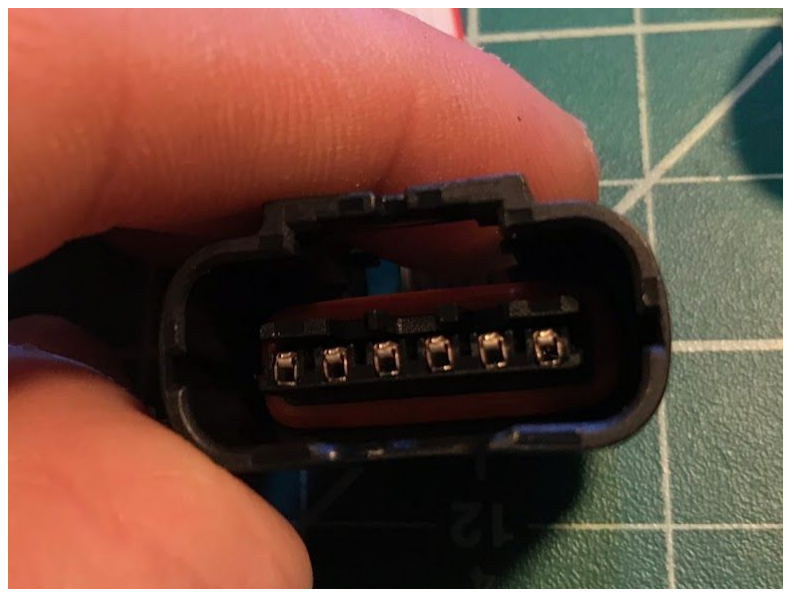
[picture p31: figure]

7. Place the included white plastic piece over the pins

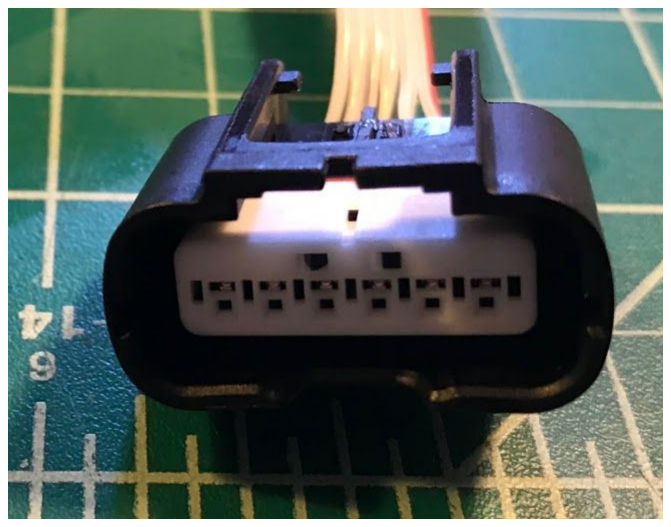
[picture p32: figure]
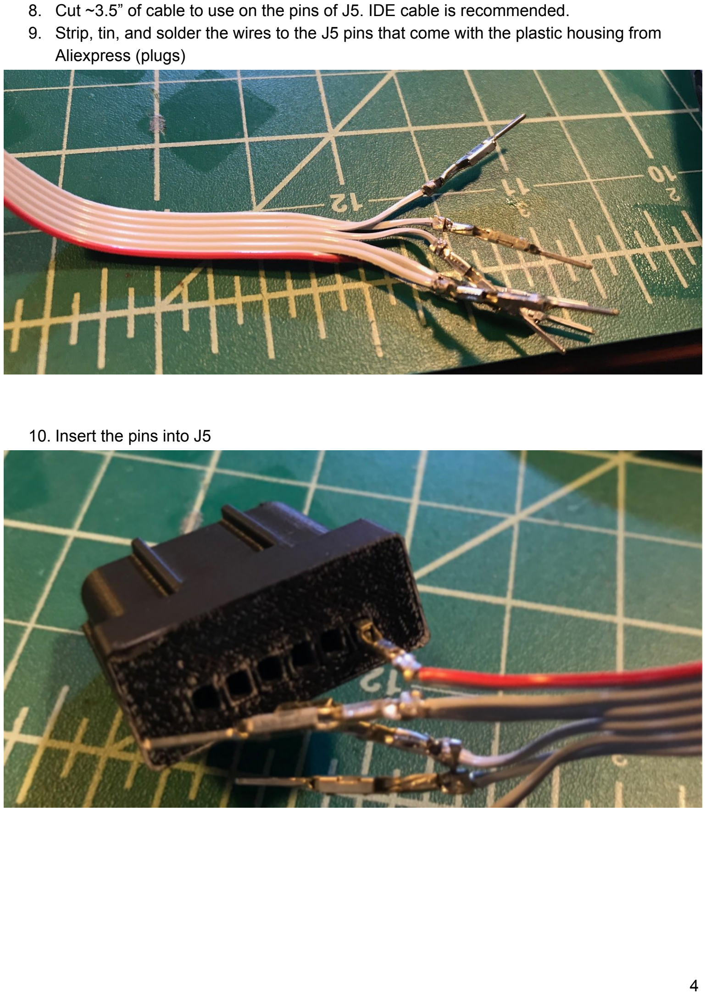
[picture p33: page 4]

8. Cut ~3.5” of cable to use on the pins of J5. IDE cable is recommended.
9. Strip, tin, and solder the wires to the J5 pins that come with the plastic housing from Aliexpress (plugs)
10. Insert the pins into J5

11. It should look like this when done. The pins should stick out slightly.

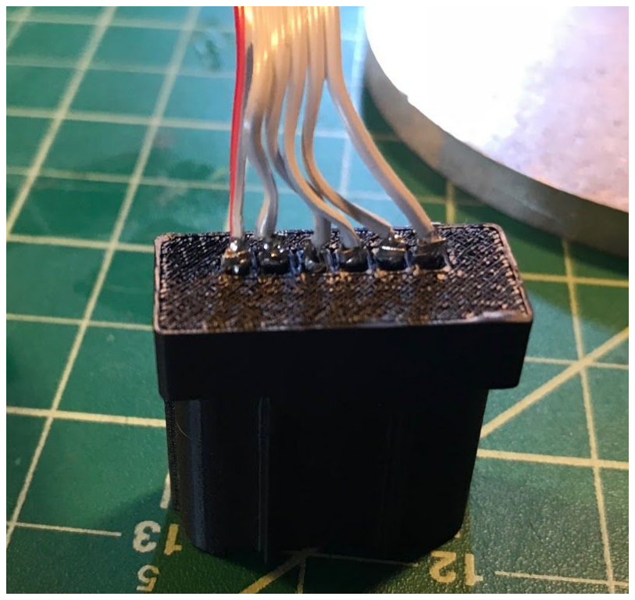
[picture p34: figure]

12. Seal the ends of the pins with a 2 part epoxy (like this) (https://smile.amazon.com/J-B-Weld-50112-ClearWeld-Quick-Setting/dp/B009EU5ZM0)

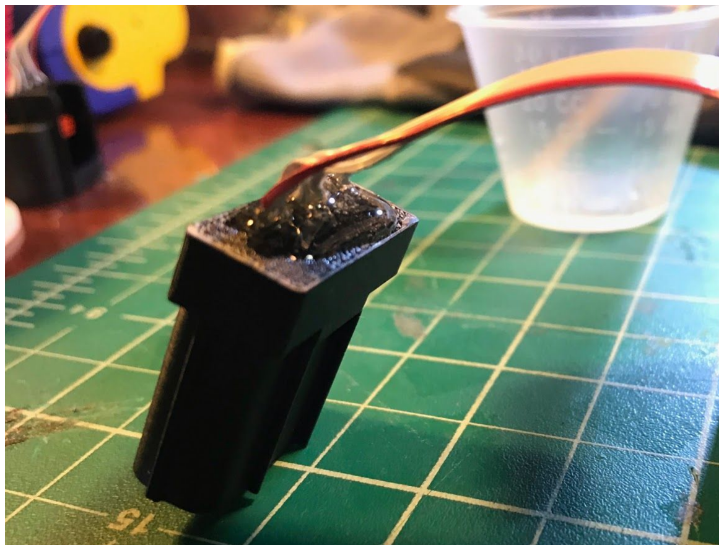
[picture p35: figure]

13. Ensure the epoxy stays on the flat part of J5 and does not drip down the sides. This will impact the fit into the case.
14. Solder J4 to the 6 holes labeled “IN” and J5 to the 6 pins holes labeled “OUT”. J4 wires should be soldered to the top side of the board and J5 wires should be soldered to the bottom side of the board.

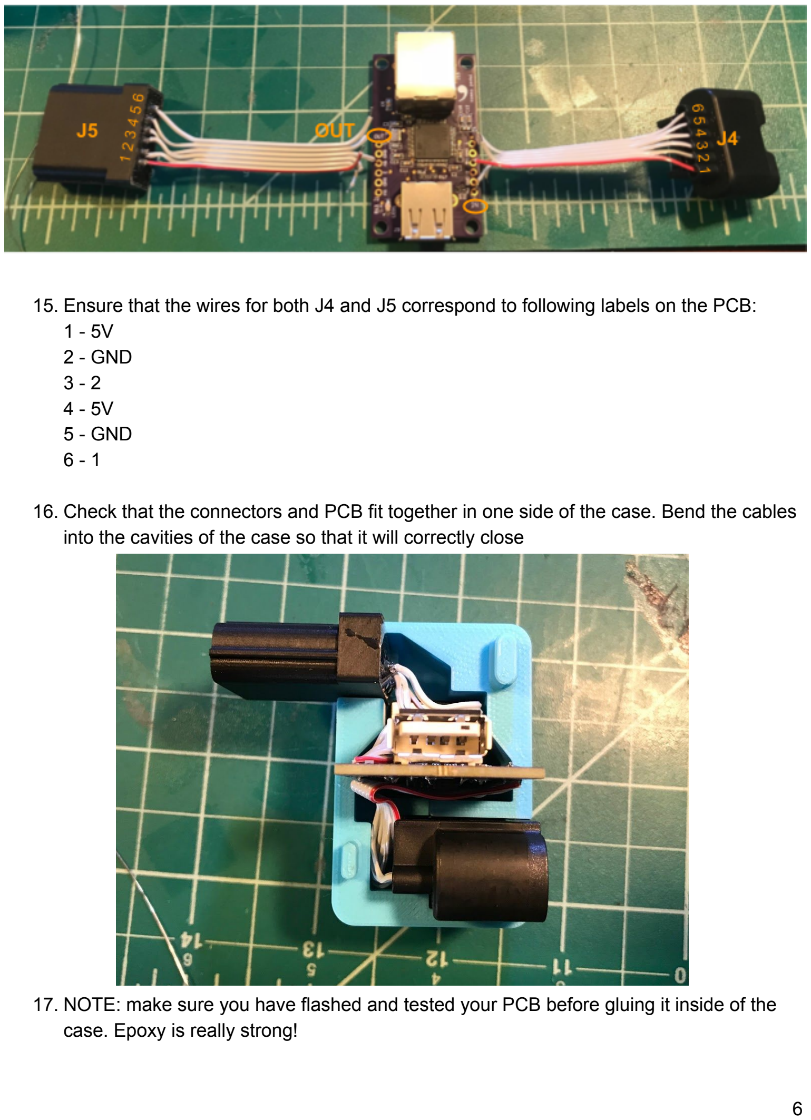
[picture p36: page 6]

15. Ensure that the wires for both J4 and J5 correspond to following labels on the PCB: 1 - 5V
2 - GND
3 - 2
4 - 5V
5 - GND
6 - 1
16. Check that the connectors and PCB fit together in one side of the case. Bend the cables into the cavities of the case so that it will correctly close
17. NOTE: make sure you have flashed and tested your PCB before gluing it inside of the case. Epoxy is really strong!

18. Put epoxy on the indicated positions of the case

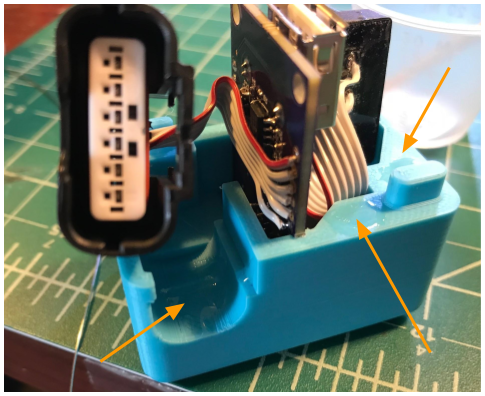
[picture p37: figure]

19. Place more epoxy on the same points on the other side of the case
20. Slide the other side of the case on and clamp in a vice while it dries
21. Wipe off any epoxy that seeps out of the case with a paper towel with alcohol on it
22. Enjoy!

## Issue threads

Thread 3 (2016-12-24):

Question.

SkipperGracie, 2016-12-24:
If I have read through all of this correctly, it seems that the only hardware you need is the Neo board, and OnePlus?

Thanks!

geohot, 2016-12-24:
And a way to keep the OnePlus cool. And a way to mount it.

Closed 2016-12-24.

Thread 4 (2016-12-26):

Can we using the newest OnePlus 3T or  ASUS ZenFone 3 Deluxe(ZS570KL) for NEOS ?

james-chou, 2016-12-26:
Can we using the newest OnePlus 3T for NEOS ?

OnePlus 3: Qualcomm® Snapdragon™ 820
OnePlus 3T with the new Qualcomm® Snapdragon™ 821 processor (2.35 GHz),

Or can we considered using ASUS ZenFone 3 Deluxe (ZS570KL) for NEOS ?

Asus is a Taiwan brand , their newest ZS570KL is also Snapdragon™ 821 with an Adreno™ 530 GPU, 6GB of RAM combined with 64GB of UFS 2.0 memory now.

ASUS ZenFone 3 Deluxe (ZS570KL):
https://www.asus.com/us/Phone/ZenFone-3-Deluxe-ZS570KL/

Thank you very much.

edsammy, 2016-12-26:
NEOS currently only supports the OnePlus3. Stay tuned for more.

geohot, 2016-12-26:
We will probably add 3T support in January.

Closed 2016-12-26.

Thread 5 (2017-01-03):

board testing: not downloading

xinlutang, 2017-01-03:
We built a NEO circuit board and tested no short in the step one in the page 16 in guide.pdf. I followed the instruction. but in step 4, I connect a 12 V adapter without plugging into a car. I also measured the 3.3V and 5.0 V test pins and all normal. When I hold on SW1, the voltage of BOOT0 change from 0 volt to 2 volts. However, I hold there for a long time, the red LED never flash. On the phone GUI, it say not board found. I did hold SW1 before I apply the power.

On the phone side, I ran it with and without the continue.sh. they is all the same. Could you tell me how long I shall hold on the sw1? I assume couple seconds shall be enough. What is other indicator I can use to check if the board is working?

edsammy, 2017-01-03:
Try testing the board without the 12V supply and just power over USB from a computer
1. hold down the button
2. with a USB extension cable, plug the board into the computer (while still holding down the button)
3. run 'lsusb' and you should see
`Bus 001 Device 012: ID 0483:df11 STMicroelectronics STM Device in DFU Mode`

This indicates that the microcontroller is live

xinlutang, 2017-01-04:
Red LED flashing now. One of my college changed the manager.py, which caused the problem.

Do I need to enable the start_all env parameter?
Thanks,

geohot, 2017-01-04:
No, the services should start when it detects that you start your car.

tsboost, 2017-01-11:
Can I sell about 1000pcs for eBay for people who are having trouble with neo board production?
If there are no legal problems, we will make neo boards and sell them at a reasonable price.

geohot, 2017-01-11:
You certainly won't have legal problems from comma.ai, as the board is MIT licensed.

gg4u, 2017-01-11:
Wow. Reading about this form Europe. Before starting, are the instructions meant only for  Qualcomm / Snapdragon 820 chips or also for other vendors? E.g. Huawei / Kirin .
Which are constraints if to adapt? (not an electric engineer here).

@tsboost if it may be a business of yours, you might want to allow boards to communicate with other chipsets.

geohot, 2017-01-11:
Board works with PC and other phones as well. 100% open source.

Adapting off 820 is pretty hard. You can get a OnePlus 3 in Europe.

tsboost, 2017-01-12:
@geohot Thank you for answer. Do you have a Neo Board update or upgrade plan?
@gg4u  Thanks. advice..

Closed 2017-01-20.

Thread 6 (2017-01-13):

How to use Cable FTDI debug

leo333, 2017-01-13:
Try testing the board without the 12V supply and just power over USB from a computer

Perform the following:

hold down the button
with a USB extension cable, plug the board into the computer (while still holding down the button)
run 'lsusb' and you should see
Bus 001 Device 012: ID 0483:df11 STMicroelectronics STM Device in DFU Mode
This indicates that the microcontroller is live

but On the phone GUI, it say not board found.  the red LED never flash.   when  plug the breakout cable into the vehicle (or 12V adapter),   green led flash once

Closed 2017-01-20.

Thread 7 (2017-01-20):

board  found  ,  not downloading

leo333, 2017-01-20:
Try testing the board without the 12V supply and just power over USB from a computer

Perform the following:

hold down the button
with a USB extension cable, plug the board into the computer (while still holding down the button)
run 'lsusb' and you should see
Bus 001 Device 012: ID 0483:df11 STMicroelectronics STM Device in DFU Mode
This indicates that the microcontroller is live

 hold down SW1 On the phone GUI, it say board not found. the red LED never flash. when plug the breakout cable into the vehicle (or 12V adapter), green led flash once

Not hold down SW1 On the phone GUI, it say board found.

edsammy, 2017-01-20:
If it says board found then all is working correctly. Is the red LED still not flashing? If so then check for shorts near the LED

leo333, 2017-01-22:
Red LED flashing now.    On the phone GUI board found.
The services should start when it detects that you start your car. is that so?

edsammy, 2017-01-23:
Correct

edsammy, 2017-02-22:
Anymore issues here?

leo333, 2017-02-22:
TKS  fixed。
I have a question, why not use Solid Cap  16v 330uf，I don't know much about the circuit。

edsammy, 2017-04-03:
If by solid you mean a ceramic capacitor like [this](https://i.stack.imgur.com/qTaTC.jpg) then the answer is because a 330uF ceramic capacitor is very expensive. They usually have much lower capacitances than their electrolytic counterparts (like the one we used).

Closed 2017-04-03.

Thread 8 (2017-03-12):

how to flash this“neos_v2.zip”

WanXiangGG, 2017-03-12:
my device is OnePlus3  but idont konw how to flash the “neos_v2.zip”to my phone

my recovery is TWRP 3.0.4

i use this recovery to flash this package ，but recovery tell me :"can't find META-INF/com/google/android/update-binary from zip "

so please tell me how to dealwith this problem .

thanks a lot!

KonradIT, 2017-03-12:
You're supposed to unzip the file in your PC and run unlock.sh or flash.sh file, if you want to do it thru recovery then unzip the file in your phone, flash system.img in TWRP (Flash > Image > Select System > FLASH), Same for boot.img (select boot in TWRP), then wipe cache+dalvik+sd card. (I personally have not tried this).

Or, you could just enable adb in your phone and run flash.sh

WanXiangGG, 2017-03-13:
But now, i find a new question.

i flashed it on my phone , the phone is power on  now.

and screen tell me  i need to "enter the URL of the NEOS program to install"

but i dont know what is the URL , so can you tell me the URL? @KonradIT

KonradIT, 2017-03-13:
@WanXiangGG I don't know, I'd put /data/data/com.termux/files/continue.sh as an URL but I am not sure. I don't have a device to test.

KonradIT, 2017-03-13:
@WanXiangGG use https://openpilot.comma.ai as the URL if you want to use Comma AI's Open Pilot.

WanXiangGG, 2017-03-13:
@KonradIT
GET !
THANK YOU!

KonradIT, 2017-03-13:
@WanXiangGG you can close this issue now.

Closed 2017-03-13.

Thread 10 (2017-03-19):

Board Found, where to see driving application screen/UI?

dchen2008, 2017-03-19:
hello, I have RED led flash, one plus3 screen show "Found board"; as attache picture:
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
Where to see driving application UI?thanks

jeankalud, 2017-03-19:
You need the ignition signal (12V) or canbus activity

yghcats, 2017-03-20:
One plus3 can only use this phone?

geohot, 2017-03-20:
OnePlus 3 and OnePlus 3T

yghcats, 2017-03-21:
@dchen2008 @geohot hi，
run over：
ssh is listening on port 8022
# ./connect.sh
to connect

Where is the mobile terminal？

 in addition ：install NEOS Program Which is the https://..... address?

thanks！

Closed 2017-03-20.

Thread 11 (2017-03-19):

Fan keep running one second to stop when plug-in rj45 12V adapter

dchen2008, 2017-03-19:
When I plug-in 12v adapter, the fan just run one second, and then stop it. Any comments? thanks.

geohot, 2017-03-20:
That's expected behavior. The fan only runs if the board detects the car is started using either the sense line or CAN packets.

dchen2008, 2017-03-20:
Got it. thanks geohot.

Closed 2017-03-20.

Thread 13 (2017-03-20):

About OBDII interfance for 2016 Acura MDX 3.5L AcuraWatch Plus Package

dchen2008, 2017-03-20:
Hello,  I plan to test the NEOS on my 2016 Acura MDX, it has back camera, front has radar detect alarm when too close front of car.
The guide.pdf page14, OBDII, missed pin-4(ignition), 7, 8. I tried to google MDX OBDII code definition, no found yet.  Do you have any kind of troubleshooting comments? or tools/docs sharing? Thanks.

edsammy, 2017-03-21:
For the 2016 MDX you can follow the pinouts described in the JAE column. However steering control is done differently in the MDX (using a communication protocol called LIN instead of CAN, similar to the Honda Accord) and the NEO hardware will not be able to control it.

Closed 2017-04-03.

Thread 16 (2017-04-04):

Add a setting to accommodate configurations without always-on power

energee, 2017-04-04:
Some 2017 Hondas; Civic hatchback and CR-V's are shipping with a different connector that only use IGN to power the camera. It would be ideal if there was a setting that could turn off the NEO when not connected to power (Or display a message that the device will turn off in a few minutes unless the user interacts) and automatically turn on when powered similar to the car's stock hardware.

I would think some users with the +12V always-on wire might prefer this since the NEO could eventually drain the battery.

Closed 2017-05-18.

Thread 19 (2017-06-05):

How do I get a Q4 of GIANTpanda

leo333, 2017-06-05:
How can I get a  Q4panda, GIANTpanda，Is GIANTpanda used to connect accord?

geohot, 2017-06-05:
GIANTpanda is a carrier board for the comma.ai panda, and it has the hardware needed to interface with accord, yes.

WaliedA, 2017-06-05:
Fantastic George, our issue is solved, can you advice on specific accord model we can test with as we are developing a GiantPanda board

geohot, 2017-06-05:
We worked with the 2016 Accord Touring. The braking and cruise are the same as the Acura, the steering is over K-Line.

WaliedA, 2017-06-11:
George, do we need Panda to use with GiantPanda for Honda Accord on connect directly to OBDII K-line

edsammy, 2017-06-13:
Yes you need a panda. GiantPanda is simply a breakout board for the panda. It lets you mount a panda in a neo.

Closed 2017-06-05.

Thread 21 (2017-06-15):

Bottom screw is too long

linagee, 2017-06-15:
I just finished assembling my neo. The bottom screw was maybe twice as long as it needed to be. (Ordered exactly as McMaster Carr list said.)

edsammy, 2017-06-28:
Can you send a picture of it sticking out? The 10mm screw seems to fit on ours!

Closed 2017-08-06.

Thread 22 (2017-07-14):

Replacement for RJ45 A-2014-2-4-LP/FS-R (AE10398-ND)

LuckyParker, 2017-07-14:
Is there another replacement for the RJ45 jack part number:A-2014-2-4-LP/FS-R (AE10398-ND)? digikey is currently out of stock. I've been looking for another component that has the same foot print as the one list in the bom, but no luck. Thank you!

edsammy, 2017-07-15:
[They're back in stock! ](https://www.digikey.com/product-detail/en/assmann-wsw-components/A-2014-2-4-LP-FS-R/AE10398-ND/2183649)

But I agree that a replacement should be found since they are only available on Digikey (and only ~1000 :/)

geohot, 2018-01-30:
Seems well stocked now.

Closed 2018-01-30.

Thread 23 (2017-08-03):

Xiaomi smartphone instead OnePlus3 ?

popurax, 2017-08-03:
- Xiaomi mi5s
- Xiaomi mi6
Can I use these instead of OnePlus3 ?

Aaahh, 2017-08-03:
Yeah looking at the sources it should be easy adding any device
I'll try doing it on a fork next week
Side note commaneos should be rebased

popurax, 2017-08-06:
😎

Aaahh, 2017-08-06:
What does that mean
I haven't started yet but I was going to tomorrow

olmerg, 2017-08-09:
Can I use Onpelus5 instead of Oneplus3?

rebroad, 2018-01-06:
@popurax I also need to know if Oneplus5 or Oneplus5T can be used instead. Is there an FAQ or stackexchange? Should one open a new issue to ask this question?

bertramt, 2018-01-08:
geohot has said more than once comma has no plans of supporting the 5 or 5T.  Basically if you want anything but the oneplus 3 or 3T, you are on your own.  My limited understanding is the visiond binary is very closely tied to the camera on the 3/3T and won't work on anything else.

Closed 2017-08-31.

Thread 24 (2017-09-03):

can anyone upload Solidworks files for given 3d STL files??

hemangjoshi37a, 2017-09-03:
I want to customize the design for myself, so i need solidworks file for the case and other 3d stuff. Your help is appreciable. Thax.

Krishtof-Korda, 2017-09-03:
You can import an stl file and solidify it in solidworks with surfacing tools such as surface offset with zero offset, or thicken. If you are unsure how to do it feel free to send me the stl and I can give you back a sldprt. Cheers!

hemangjoshi37a, 2017-09-03:
Okay but that won't have solidworks supported features, that will only have
surfaces. I want to edit features..

On Sun, Sep 3, 2017, 12:59 PM Krishtof Korda <notifications@github.com>
wrote:

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
--

Regards,
Hemang Joshi

Krishtof-Korda, 2017-09-03:
Actually it will give you exactly what you want. After you copy the
surfaces, knit everything together you can convert to solid, then you can
run feature recognition tool. You will have a solid body with features. It
won't be the original features that were modeled but you will be able to
modify the solid body and add your own features. Let me know if you need
help, just send me the stl and I can send it back as solid with features.

Cheers,

Krishtof

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

Closed 2018-01-30.

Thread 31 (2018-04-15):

It is possible to combine Honda's and Toyota's giraffe in the same circuit board?

cruise0, 2018-04-15:
giraffe is an open hardware project, but Honda's and Toyota's giraffe are using different circuit layout
however I wonder about  it is possible to combine these 2 hardware into one.

If not, what reasons cause they must be 2 different hardware?

bertramt, 2018-04-17:
Not sure if it's possible or worthwhile.  Honda and Toyota use different connectors to connect to the car.  If you wanted all 4 connectors (2 honda and 2 toyota) in addition to the panda connector it becomes a much bigger board.  Some vehicles don't have room for a bigger board.  A giraffe is a vehicle adapter and it generally makes sense to keep it separate for each make/model with different requirements to keep complexity low and board size smaller.

With that said it's open source if you really want it on one board your probably going to have to lead that effort yourself.

Closed 2018-08-07.

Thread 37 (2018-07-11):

Toyota giraffe BOM Ref des is incorrect for two item

xx979xx, 2018-07-11:
according to giraffe12.sch,  J1 is a female (has no pin) goes to camera but the part listed in BOM.csv
is a male connector goes to main wiring. also, J2 is a male but the part listed is a female.

vanillagorillaa, 2018-11-13:
Fixed in latest commit

Closed 2018-11-13.

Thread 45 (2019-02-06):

BOM for Hyundai has error

emmertex, 2019-02-06:
BOM mentions a part for a 0.12 ohm resistor, but schematic mentions the correct size of 120ohm

rbiasini, 2019-02-06:
Nice catch. @vanillagorillaa

vanillagorillaa, 2019-02-06:
Fixed in latest commit

Closed 2019-02-06.

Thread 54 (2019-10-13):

Hyundai Giraffe pinout is incorrect

xx979xx, 2019-10-13:
the male connector is inconsistent with the female connector
According to official Hyundai and community diagrams for female connector:
pin3: CAN2_L and pin11: CAN2_H but it the other way around in /giraffe/hyundai/Hyundai_Giraffe.sch.pdf
the same also for pin4: CAN1_L and pin12: CAN1_H

vanillagorillaa, 2019-10-19:
Hmmm odd, we built this for our santa fe (which we sold and no longer have) and this design worked.

xx979xx, 2019-10-20:
it is likely just a display issue. the package numbering is like this (5-1-6-2-7-8-9-10-3-11-4-12)
could you plz confirm the pinout for the female connector?

Closed 2020-11-18.

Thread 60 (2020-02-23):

Voltage expectations on OBD-C

JasonJShuler, 2020-02-23:
The pinout for the OBD-C does not specify the voltage expected for the VIN pins

csouers, 2020-03-01:
That's more of a limitation at the host end of the cable, which we'll consider is the comma two. Has that spec been released for the uno board? It's probably similar to the other pandas, but maybe different due to miniaturization. Somewhere around 10v - 18v?

robbederks, 2020-03-01:
Anything between 8 and 18V should be fine!

Closed 2020-03-01.

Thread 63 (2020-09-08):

OBD-2 Harness schematic

JasonJShuler, 2020-09-08:
Can we please get the OBD-II harness connector schematic added?

Thanks!

ErichMoraga, 2020-09-08:
It is there already.

robbederks, 2020-09-15:
The OBD-II harness schematic (the one with GMLAN) is closed source.

As a brief general description though:
It's basically a conversion between the OBD-II spec and the OBD-C spec, consisting of:
- It connects all 3 possible CAN buses (see [this pinout](https://miro.medium.com/max/484/1*UfvsgwapNIg4fpO0iz3xBg.png)) in order to bus 0, 1 and 2 on the OBD-C side
- It detects ignition and converts that to ignition for the OBD-C spec
- It implements a mean of orientation detection for the OBD-C spec
- It has an active bi-directional conversion circuit between the GMLAN pin on the OBD-II connector and CAN bus 3 of OBD-C. This conversion circuit is powered only when the `relay power` is enabled from the OBD-C spec

Let me know if you have any further questions!

JasonJShuler, 2020-09-16:
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

I am attempting to develop the harness wiring for GM vehicles that have the cyber security gateway which means the OBD2 port is useless and that do not have an ascm. this bi-directional low-speed GM lan have circuit is something that would be very useful have. I have put countless hours into this project and closed sourcing something like this feels like a real slap in the face. It's not right. Is not your goal to have more cars supported? why would you hide the implementation details of a connector?

I understand that you have a business to run. But you're relying on a community to Port vehicles and then you tie our hands. I am providing you guys with free labor and you're going to close source the OBD2 adapter that contains the exact circuit that I need wow that is pretty trashy.

JasonJShuler, 2020-09-16:
My apologies for my we'll call it cranky comment which I have deleted; at the time I did not understand that the OBD-II harness was a complete replacement of the harness used for other vehicles I thought it was an attachment for that harness that's why I was ticked off sorry about that.

Closed 2020-09-15.

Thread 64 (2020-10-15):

Comma key schematic

JasonJShuler, 2020-10-15:
Can we please get the schematic and pcb layout for the Comma Key? Or just the schematic?

Thanks!

vanillagorillaa, 2020-11-21:
b0f3a29ad6bc9f65c1329f611b49973e76a4e616

Closed 2020-11-21.

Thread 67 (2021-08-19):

Bosch Harness Camera connector doesn't exist?

arnarhelgi, 2021-08-19:
JAE MX34M125SF1 does not exist as far as I can see, and can't be found on mouser / digikey or even in the JAE catalog, the part number seems to be invalid and the 12 pin connector from this series does not match that connector. Is there another part  that's available?

csouers, 2021-08-22:
It's not available via retail. You have to contact JAE sales directly.

arnarhelgi, 2021-08-22:
I see, I assume that JAE will only deal in bulk? I need one, maybe two make/female connectors and pins. I’ll try them, or hope and pray that my civic has a nidec camera unit… 😬

csouers, 2021-08-22:
Based on how comma was able to source them, yeah. Bulk seems to be the key.

vanillagorillaa, 2021-08-23:
Looks like there is a typo in the diagram, will update accordingly  The correct part number is MX34M12SF1. Mouser has 820 in stock and will sell single quantities.

vanillagorillaa, 2021-08-23:
Fixed in 92b9dc17b63c4b0328dfe4ce6999eeced0f1c992

Closed 2021-08-23.

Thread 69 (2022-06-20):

Diagram error or misunderstanding on J533

actuallylemoncurd, 2022-06-20:
Hello, on the J533 Diagram, the pinout for "To Adapter Board" is what I assume to be the car harness j533 plug.

The counting and display of those pins are wrong.
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

theyre going
1 3 5
2 4 6
when its supposed to be
1   2   3
11 12 13

Please look at how the pinout for "TO j533" is displayed as that is how VW counts their pins on the car harness side

vanillagorillaa, 2022-06-21:
The adapter board has two connectors on it, 5018762040 and 966871-1. 966871-1 number scheme is 1 2 3, 11 12 13, but the numbering scheme for 5018762040 is 1 3 5, 2 4 6. The J533 harness connects to the adapter board with connector part number 5016462000 which is why it is on the harness schematic this way.

You can find the adapter board here, https://github.com/commaai/neo/tree/master/car_harness/boards/VW

actuallylemoncurd, 2022-07-01:
what is the point of the "adapter board?"

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

The J533 harness from your shop does not use this "adapter board" but rather a normal wire-wire plug

I am trying to find the pinout used for the j533 DEV harness sold on your shop.
I already have one installed but I'd like to know which buss's are filtered/tapped/etc

actuallylemoncurd, 2023-05-11:
hello, 5016462000 is the PN listed in the PDF, not  5018762040.

i only noticed this after buying  5018762040........

the PCB counterpart of 5016462000 is 5018762640

actuallylemoncurd, 2023-05-12:
wait now im confused. mouser says 5018762040 is the right mating connector. i have confirmed by PN that 5018762040 is what i ordered, and it is NOT the same as the one on my comma PCB

@vanillagorillaa did you guys change the production J533 connector?
if so, can you update the PDF or drop the new PN here?

i am trying to make a module to add some functionality to OP

actuallylemoncurd, 2023-05-12:
yeah just triple checked,  5018762040 is what i bought, and it is different than that of the connector on my genuine comma ai j533 adapter PCB from the harness purchased with my C3.

any help?

Closed 2022-06-21.

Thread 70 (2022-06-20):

CAN number count mismatch

actuallylemoncurd, 2022-06-20:
Comma pedal pinout shows it is "CAN1" mean while on the official relay pinout it is "CAN0"

Seems there is a discrepency of which number was used to count from, 0 vs 1

Pedal:
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

Relay:
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

ErichMoraga, 2022-06-20:
As a side note, Pedal and Giraffe were used fake ethernet spec v1, whereas the Harness [relay] Box and CPv2 (Comma Power version two) use fake ethernet spec v2.

vanillagorillaa, 2022-06-21:
Not really an issue, other older hardware in this repo also have this same discrepancy. As long as the single CAN bus on the pedal is routed to pins 3/6 on ethernet connector it will work.

Closed 2022-06-21.

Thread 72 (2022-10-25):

CAN in harnesses

eried, 2022-10-25:
Hi, when a harness has the canbuses duplicated like: https://github.com/commaai/neo/blob/master/car_harness/Type_I_Hyundai_Car_Harness.sch.pdf (CAN1 is twice in the lower left connector) is that an error or is actually like that?

vanillagorillaa, 2022-12-15:
Yes, this is normal, we do not split CAN1 like we split 0/2. CAN1 is typically radar CAN that we just want to read from.

Closed 2022-12-15.

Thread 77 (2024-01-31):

J533 Harness wrong annotations

andiradulescu, 2024-01-31:
As reported by `Mr.One` on [Discord](https://discord.com/channels/469524606043160576/534359517836607488/1199005902058041487), it seems the [J533 Harness](https://github.com/commaai/neo/blob/master/car_harness/J533_Harness.sch.pdf) annotations for `1534102-1 TO J533` and `5016462000 TO ADAPTER BOARD` have `CAN0_L/CAN0_H` mixed up with `CAN2_L/CAN2_H`.

`Mr.One` already made the harness and proved the modification was [correct](https://discord.com/channels/469524606043160576/534359517836607488/1199369713801764894).

I investigated this further and I believe the same [thing](https://discord.com/channels/469524606043160576/534359517836607488/1202181830514581535).

robbederks, 2024-08-01:
You were correct, we just noticed the same thing internally.
I've fixed both the v1 and v3 schematics: https://github.com/commaai/neo/commit/6160ea6ca2cc2b655366ed53e8e1aaab5b633101

Apologies it took this long!

Closed 2024-08-01.

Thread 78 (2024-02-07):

2018-2023 Nissan Leaf wiring harness info

gellis12, 2024-02-07:
Per my discussion with @sshane, I'm adding some info here:

For some brief context, the Leaf does not have you connect the Comma wiring harness adapter at the LKAS camera, it gets connected at the ADAS computer module instead. This module is typically located behind the glovebox on the passenger side, though it is sometimes located behind the dashboard in a small number of markets.

The ADAS computer does not have constant fused 12v power supplied to it, but it does get switched 12v ([Ref 1](https://www.nissan-techinfo.com/refgh0v/sm/2023/LEAF/SM23EA0ZE1U1/eWD/vehicle/htmlsrc/fig.html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)). Currently, this means that the Comma Power is required to provide power to the Comma 3 while the vehicle is switched off. However, the TPMS controller is physically located very close to the ADAS computer behind the glovebox (most Leaf users actually mount the wiring harness adapter onto the body of the TPMS controller), and it does have constant 12v supplied to it ([Ref 2](https://www.nissan-techinfo.com/refgh0v/sm/2023/LEAF/SM23EA0ZE1U1/eWD/vehicle/htmlsrc/fig.html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)).

We have also confirmed that the Comma 3 is able to successfully fingerprint the vehicle without the CANbus lines provided by the Comma power. If there is a desire to phase out the Comma Power in the future, it should be possible to just add a second set of connectors to the wiring harness adapter in order to get constant fused 12v power from the TPMS controller. This would require less effort for users to install compared to the current solution which involves feeding the ethernet cable through the middle of the dashboard to reach the OBD-2 port on the drivers side.

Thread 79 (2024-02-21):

Mazda adapter board missing?

dzid26, 2024-02-21:

robbederks, 2024-08-01:
Has been added! https://github.com/commaai/neo/tree/master/car_harness/v3/adapter_pcbs/mazda

It's the same pinout as on the v1, so should be compatible with either version.

Closed 2024-08-01.

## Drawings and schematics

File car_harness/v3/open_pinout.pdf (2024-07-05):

# FUNCTIONAL DIAGRAM

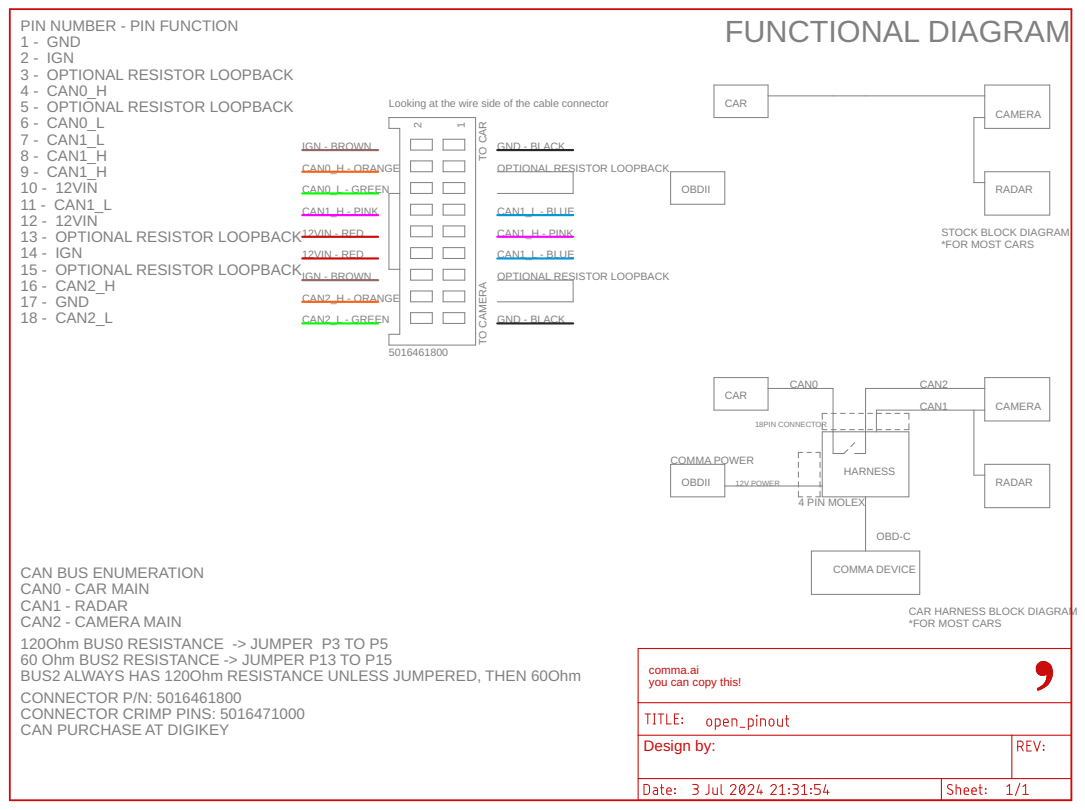
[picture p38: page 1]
GND - BLACK; IGN - BROWN; CAN1_L - BLUE; CAN0_L - GREEN; CAN2_L - GREEN; CAN0_H - ORANGE; CAN2_H - ORANGE; CAN1_H - PINK; 12VIN - RED; PIN NUMBER - PIN FUNCTION 1 - GND 2 - IGN 3 - OPTIONAL RESISTOR LOOPBACK 4 - CAN0_H 5 - OPTIONAL RESISTOR LOOPBACK 6 - CAN0_L 7 - CAN1_L 8 - CAN1_H 9 - CAN1_H 10 - 12VIN 11 - CAN1_L 12 - 12VIN 13 - OPTIONAL RESISTOR LOOPBACK 14 - IGN 15 - OPTIONAL RESISTOR LOOPBACK 16 - CAN2_H 17 - GND 18 - CAN2_L; CAR; OBDII; HARNESS; COMMA DEVICE; CAMERA; RADAR; CAN0; CAN2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

Looking at the wire side of the cable connector

MERA TO CAR OPTIONAL RESISTOR LOOPBACK
GND - BLACK

STOCK BLOCK DIAGRAM
*FOR MOST CARS

CAN1_L - BLUE
OPTIONAL RESISTOR LOOPBACK

CAN BUS ENUMERATION
CAN0 - CAR MAIN
CAN1 - RADAR
CAN2 - CAMERA MAIN
120Ohm BUS0 RESISTANCE -> JUMPER P3 TO P5
60 Ohm BUS2 RESISTANCE -> JUMPER P13 TO P15
BUS2 ALWAYS HAS 120Ohm RESISTANCE UNLESS JUMPERED, THEN 60Ohm
CONNECTOR P/N: 5016461800
CONNECTOR CRIMP PINS: 5016471000
CAN PURCHASE AT DIGIKEY

CAR HARNESS BLOCK DIAGRAM

comma.ai
you can copy this!

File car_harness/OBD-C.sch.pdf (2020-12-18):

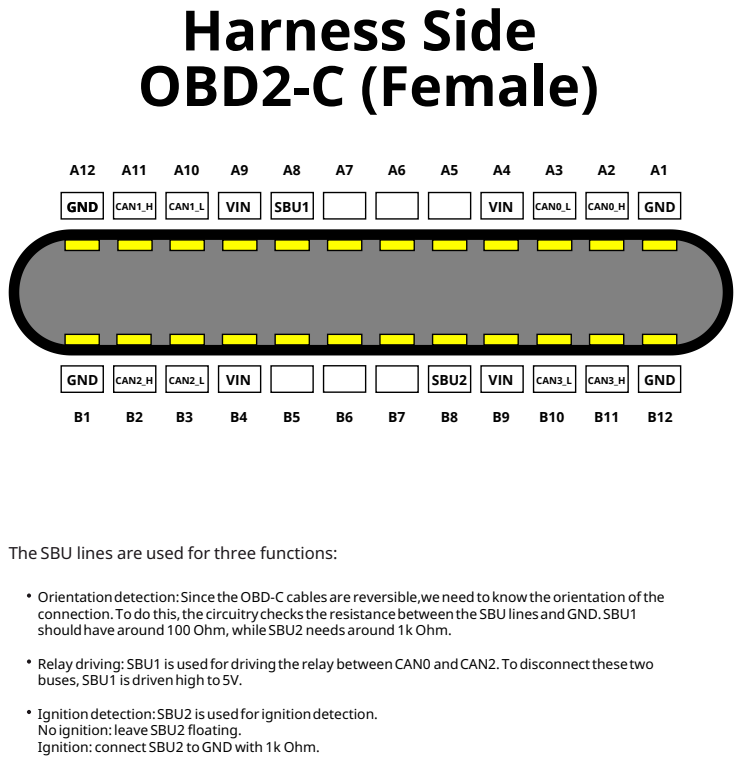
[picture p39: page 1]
GND; VIN; SBU2 VIN; GND CAN1_H CAN1_L; SBU1; VIN CAN0_L; CAN2_H CAN2_L; CAN3_L CAN3_H; CAN0_H; Harness Side OBD2-C (Female)

The SBU lines are used for three functions:

Orientationdetection:Sincethe OBD-C cables are reversible,weneedtoknowthe orientation ofthe
connection.Todo this,the circuitrychecks the resistancebetweenthe SBU linesandGND.SBU1
shouldhave around 100 Ohm, whileSBU2 needs around 1k Ohm.
Relay driving: SBU1 is usedfordrivingthe relay betweenCAN0 andCAN2.Todisconnectthesetwo
buses, SBU1 is drivenhigh to5V.
Ignitiondetection:SBU2 is usedfor ignitiondetection.
Noignition: leave SBU2 floating.
Ignition: connect SBU2 toGND with 1k Ohm.

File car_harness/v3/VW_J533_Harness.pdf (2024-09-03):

## TO CAR TO GATEWAY

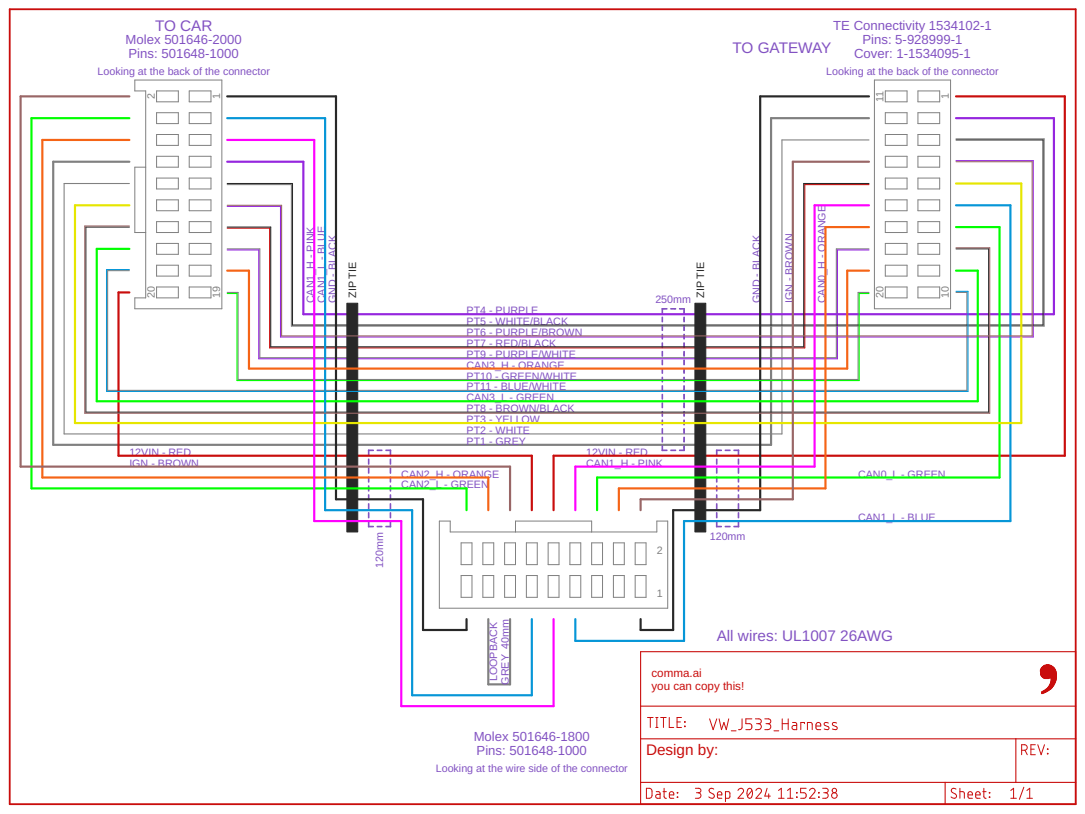
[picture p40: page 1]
Design by:; OPBACK GREY 40m; All wires: UL1007 26AWG; GND - BLACK; CAN0_L - GREEN; CAN1_L - BLUE; CAN0_H - ORANGE; CAN1_H - PINK; IGN - BRO; Molex 501646-1800 Pins: 501648-1000; IGN - BROWN; PT4 - PURPLE; ZIP TIE

TE Connectivity 1534102-1
Pins: 5-928999-1
Cover: 1-1534095-1
Looking at the back of the connector

Looking at the back of the connector Molex 501646-2000
Pins: 501648-1000

CAN1_L - BLUE CAN1_H - PINK GND - BLACK

PT5 - WHITE/BLACK
PT6 - PURPLE/BROWN
PT7 - RED/BLACK
PT9 - PURPLE/WHITE
CAN3_H - ORANGE
PT10 - GREEN/WHITE
PT11 - BLUE/WHITE
CAN3_L - GREEN
PT8 - BROWN/BLACK
PT3 - YELLOW
PT2 - WHITE
PT1 - GREY

12VIN - RED | | 12VIN - RED

CAN2_H - ORANGE
CAN2_L - GREEN

comma.ai
you can copy this!

Looking at the wire side of the connector

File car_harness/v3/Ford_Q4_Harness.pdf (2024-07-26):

## TO CAR

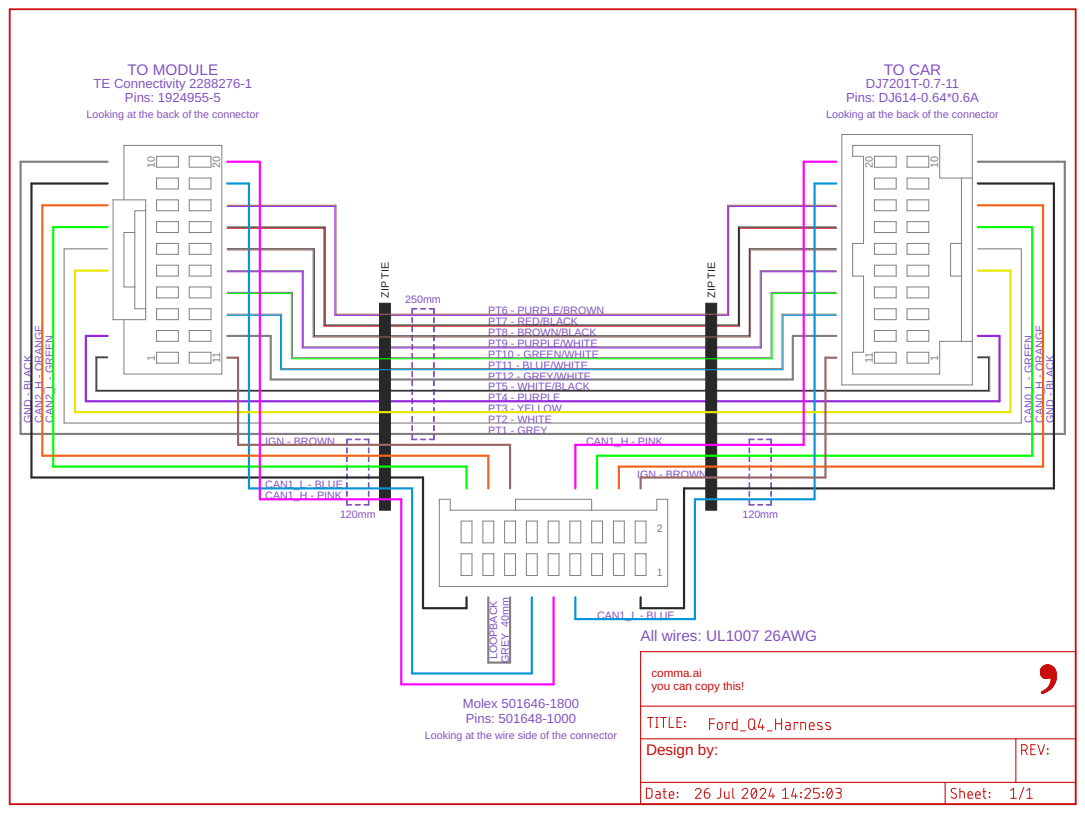
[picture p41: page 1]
Design by:; OPBACK GREY 40m; All wires: UL1007 26AWG; CAN0_H - ORANGE; Molex 501646-1800 Pins: 501648-1000; TE Connectivity 2288276-1 Pins: 1924955-5; CAN1_L - BLUE; CAN1_H - PINK; PT9 - PURPLE/WHITE PT10 - GREEN/WHITE PT11 - BLUE/WHITE PT12 - GREY/WHITE; PT8 - BROWN/BLACK; PT7 - RED/BLACK; PT6 - PURPLE/BROWN; PT5 - WHITE/BLACK; ZIP TIE

CAN2_H - ORANGE CAN2_L - GREEN GND - BLACK TO MODULE

Looking at the back of the connector DJ7201T-0.7-11
Pins: DJ614-0.64*0.6A

Looking at the back of the connector

GND - BLACK CAN0_L - GREEN

PT4 - PURPLE
PT3 - YELLOW
PT2 - WHITE
PT1 - GREY

IGN - BROWN CAN1_H - PINK

IGN - BROWN

CAN1_L - BLUE

comma.ai
you can copy this!

Looking at the wire side of the connector

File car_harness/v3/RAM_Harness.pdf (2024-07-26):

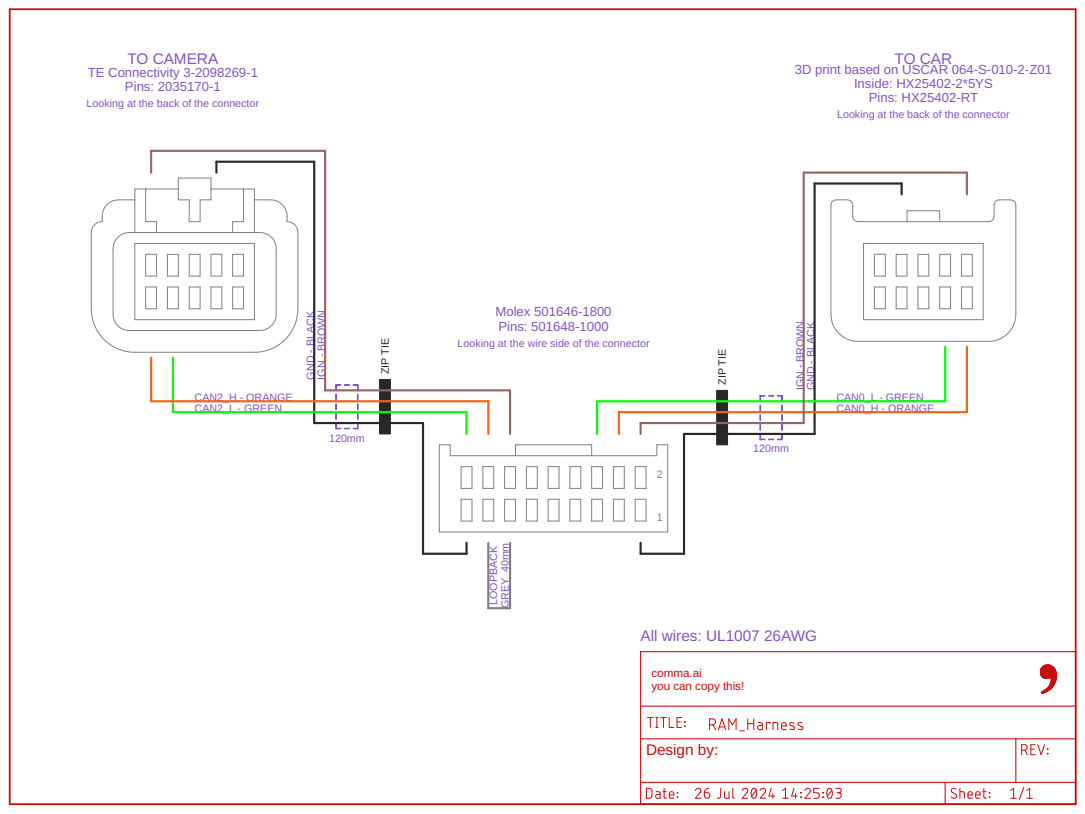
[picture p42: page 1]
Design by:; TO CAMERA; TO CAR; TE Connectivity 3-2098269-1 Pins: 2035170-1; OPBACK GREY 40m; All wires: UL1007 26AWG; CAN0_H - ORANGE; IGN - BRO; Molex 501646-1800 Pins: 501648-1000; GND - BLACK IGN - BRO; CAN2_L - GREEN; CAN2_H - ORANGE; Inside: HX25402-2*5YS Pins: HX25402-RT; ZIP TIE

Looking at the back of the connector 3D print based on USCAR 064-S-010-2-Z01

Looking at the back of the connector

GND - BLACK CAN0_L - GREEN

Looking at the wire side of the connector

comma.ai
you can copy this!

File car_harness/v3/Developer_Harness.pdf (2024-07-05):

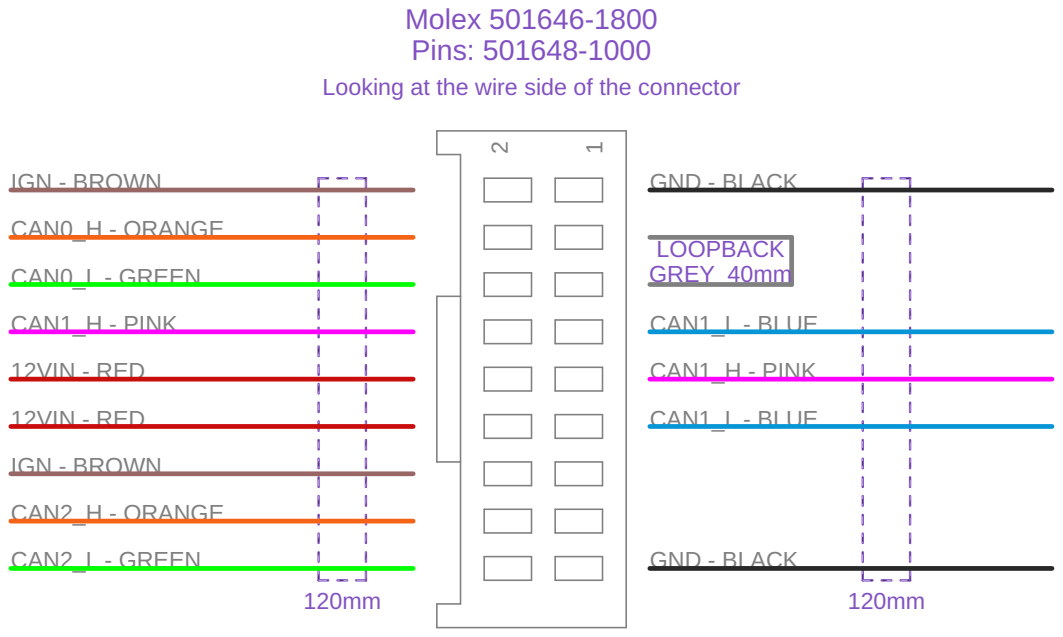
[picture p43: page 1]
GND - BLACK; IGN - BROWN; CAN1_L - BLUE; CAN0_L - GREEN; CAN2_L - GREEN; CAN0_H - ORANGE; CAN2_H - ORANGE; CAN1_H - PINK; 12VIN - RED; Design by:; LOOPBACK GREY 40mm; Molex 501646-1800 Pins: 501648-1000

Looking at the wire side of the connector

comma.ai
you can copy this!

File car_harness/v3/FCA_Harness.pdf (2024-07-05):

## TO CAR

## TO CAMERA

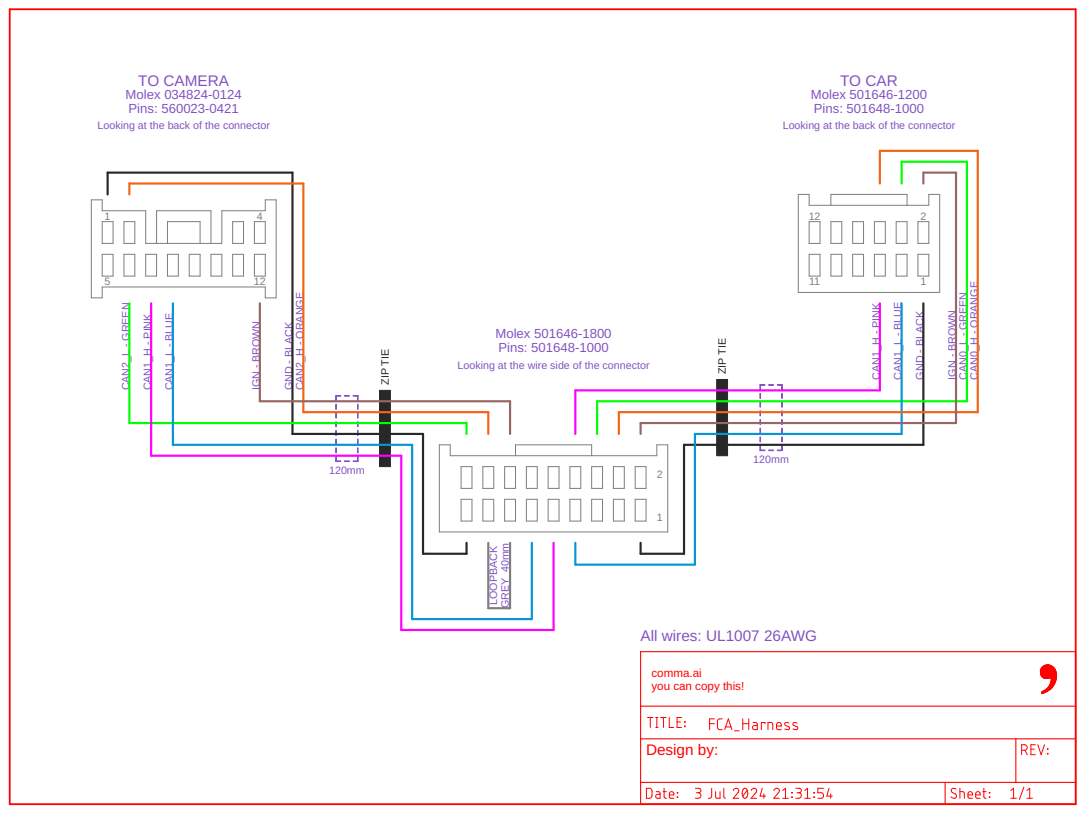
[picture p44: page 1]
Design by:; OPBACK GREY 40m; All wires: UL1007 26AWG; CAN1_L - BLUE CAN0_H - ORANGE; CAN1_H - PINK; IGN - BRO; Molex 501646-1800 Pins: 501648-1000; CAN1_L - BLUE CAN1_H - PINK; GND - BLACK; CAN2_L - GREEN; CAN2_H - ORANGE; ZIP TIE

Molex 034824-0124
Pins: 560023-0421
Looking at the back of the connector

Looking at the back of the connector Molex 501646-1200
Pins: 501648-1000

GND - BLACK CAN0_L - GREEN

Looking at the wire side of the connector

comma.ai
you can copy this!

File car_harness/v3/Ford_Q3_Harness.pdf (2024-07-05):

## TO CAR

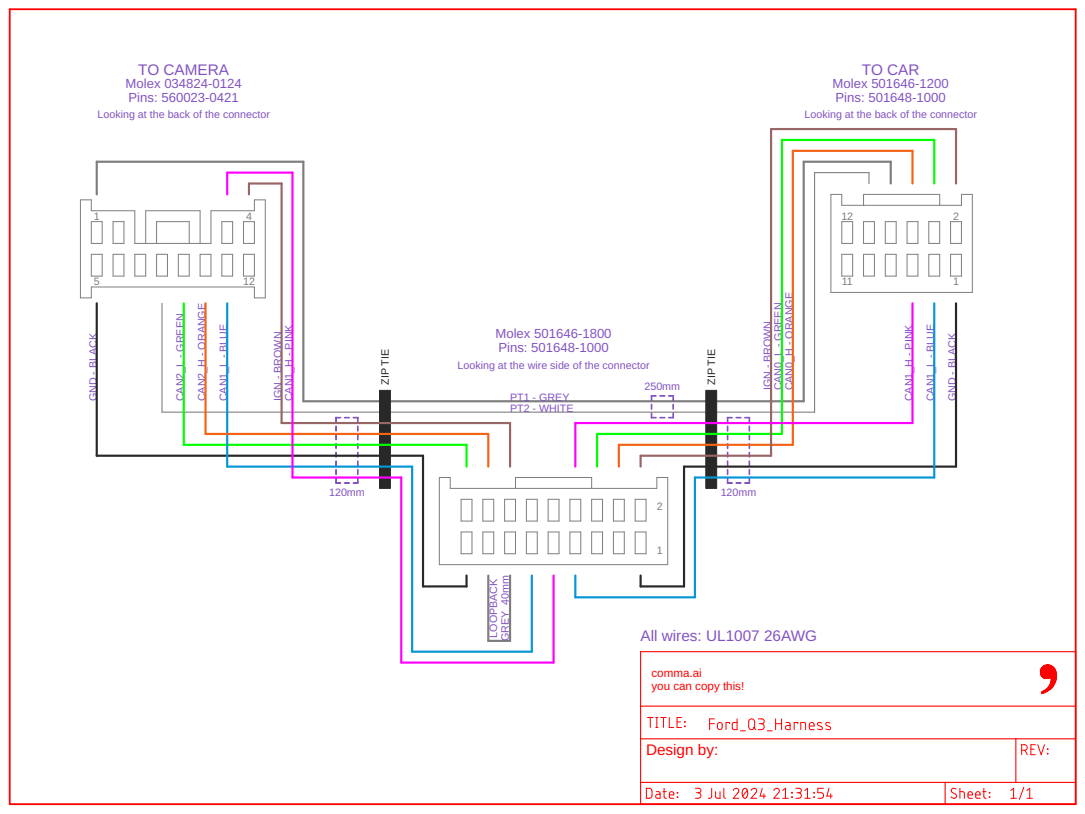
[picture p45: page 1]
Design by:; OPBACK GREY 40m; All wires: UL1007 26AWG; GND - BLACK; CAN0_L - GREEN; CAN0_H - ORANGE; Molex 501646-1800 Pins: 501648-1000; PT2 - WHITE; PT1 - GREY; CAN2_H - ORANGE CAN2_L - GREEN; CAN1_L - BLUE CAN1_H - PINK; IGN - BRO; ZIP TIE

GND - BLACK TO CAMERA
Molex 034824-0124
Pins: 560023-0421
Looking at the back of the connector

Looking at the back of the connector Molex 501646-1200
Pins: 501648-1000

Looking at the wire side of the connector

comma.ai
you can copy this!

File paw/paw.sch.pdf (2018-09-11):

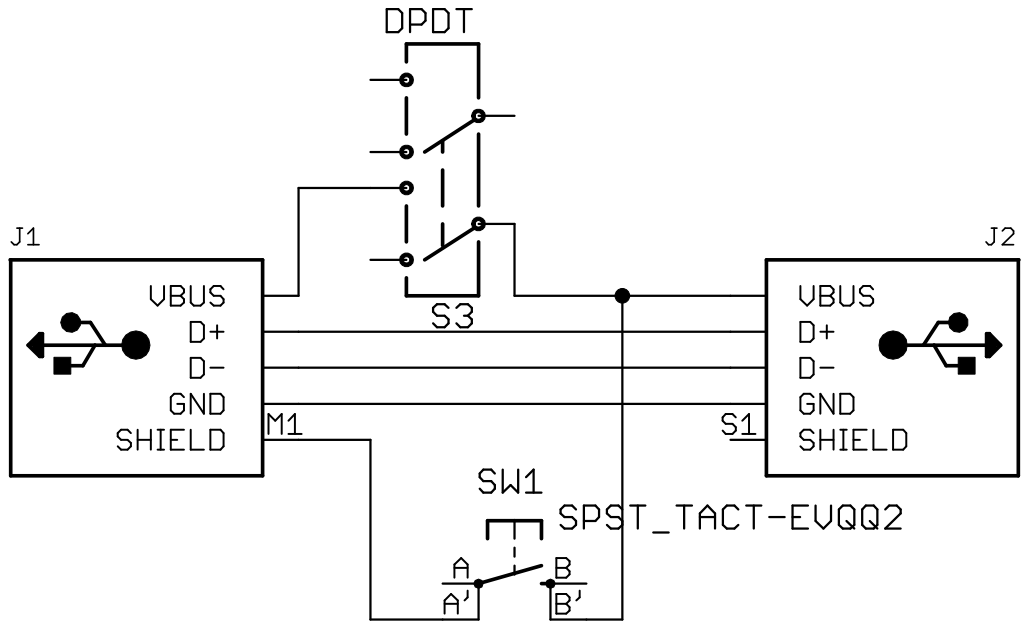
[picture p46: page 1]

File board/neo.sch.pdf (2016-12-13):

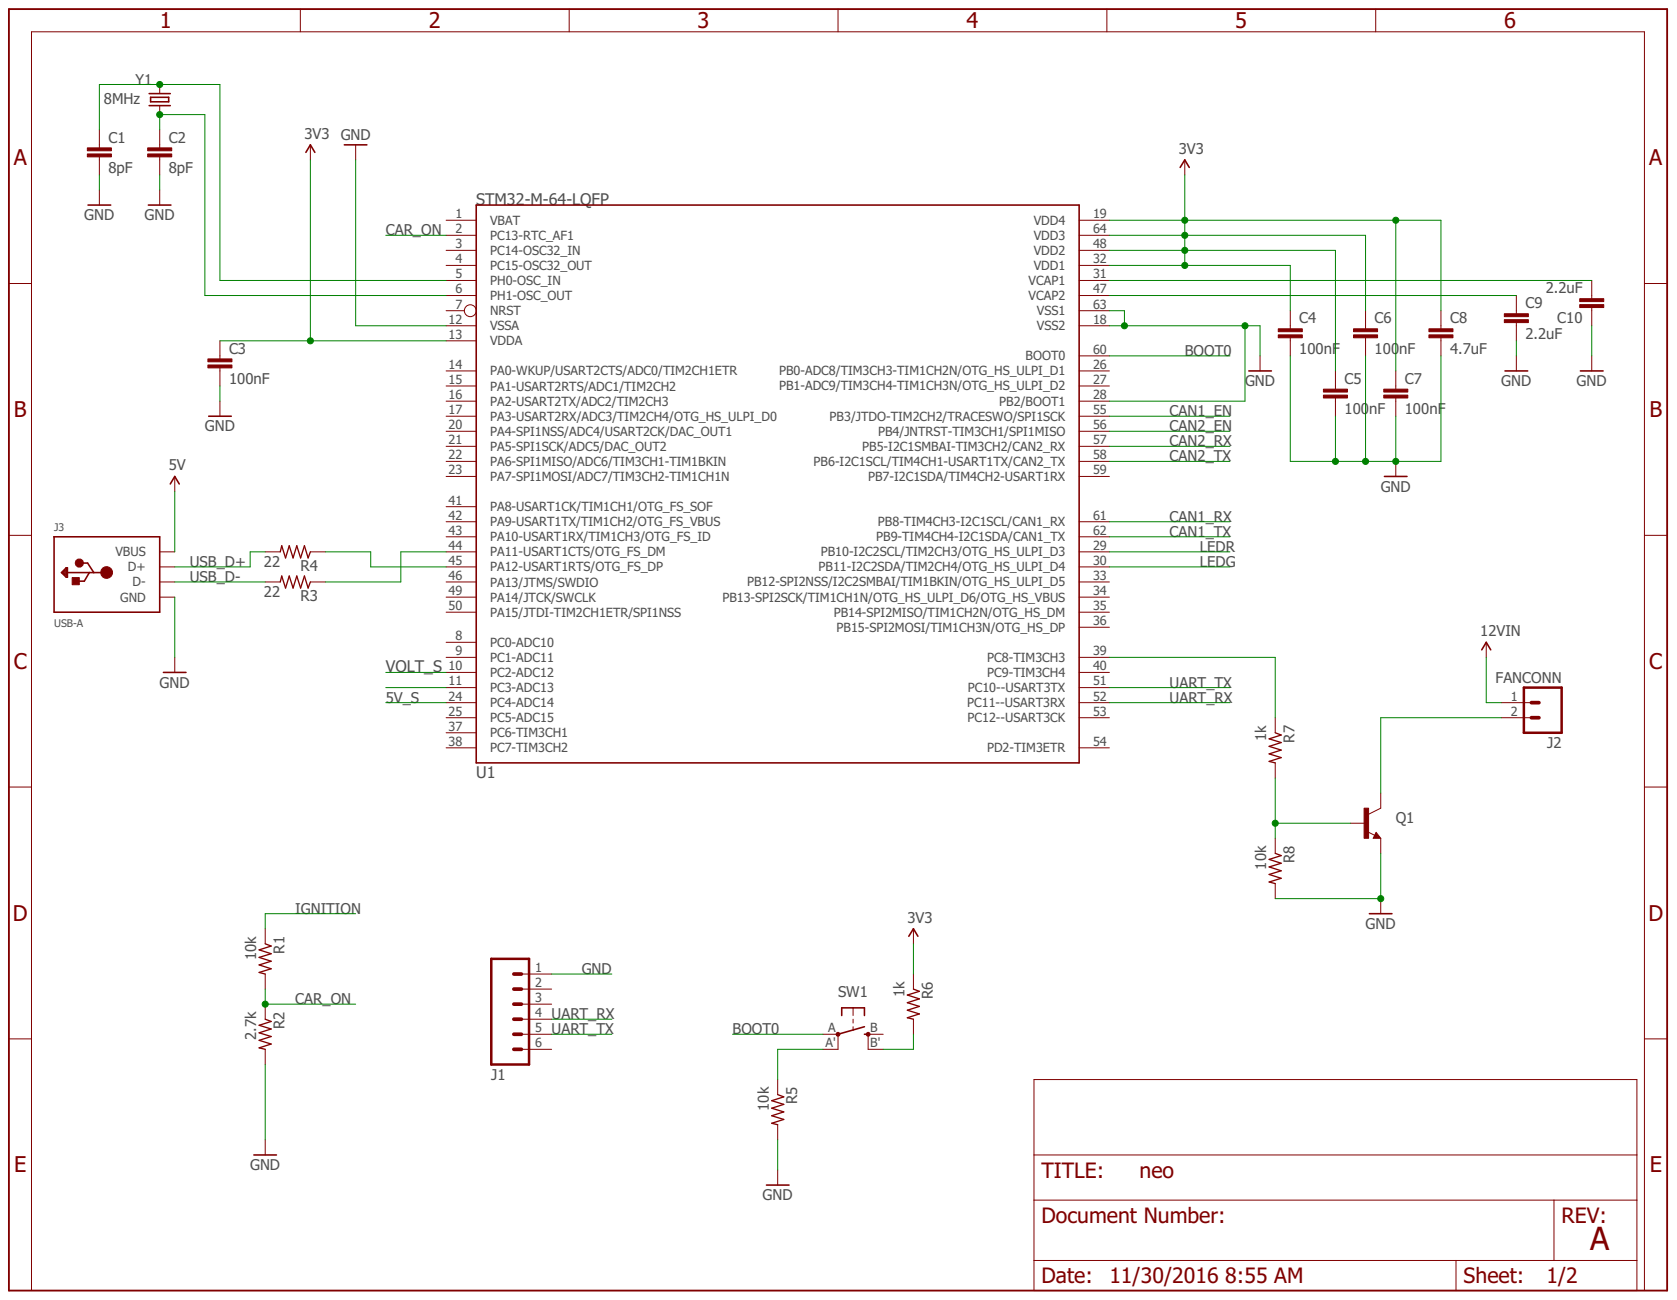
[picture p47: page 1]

64
48

47 VDD2 32

Document Number: | REV: A

Date: 11/30/2016 8:55 AM | Sheet: 1/2

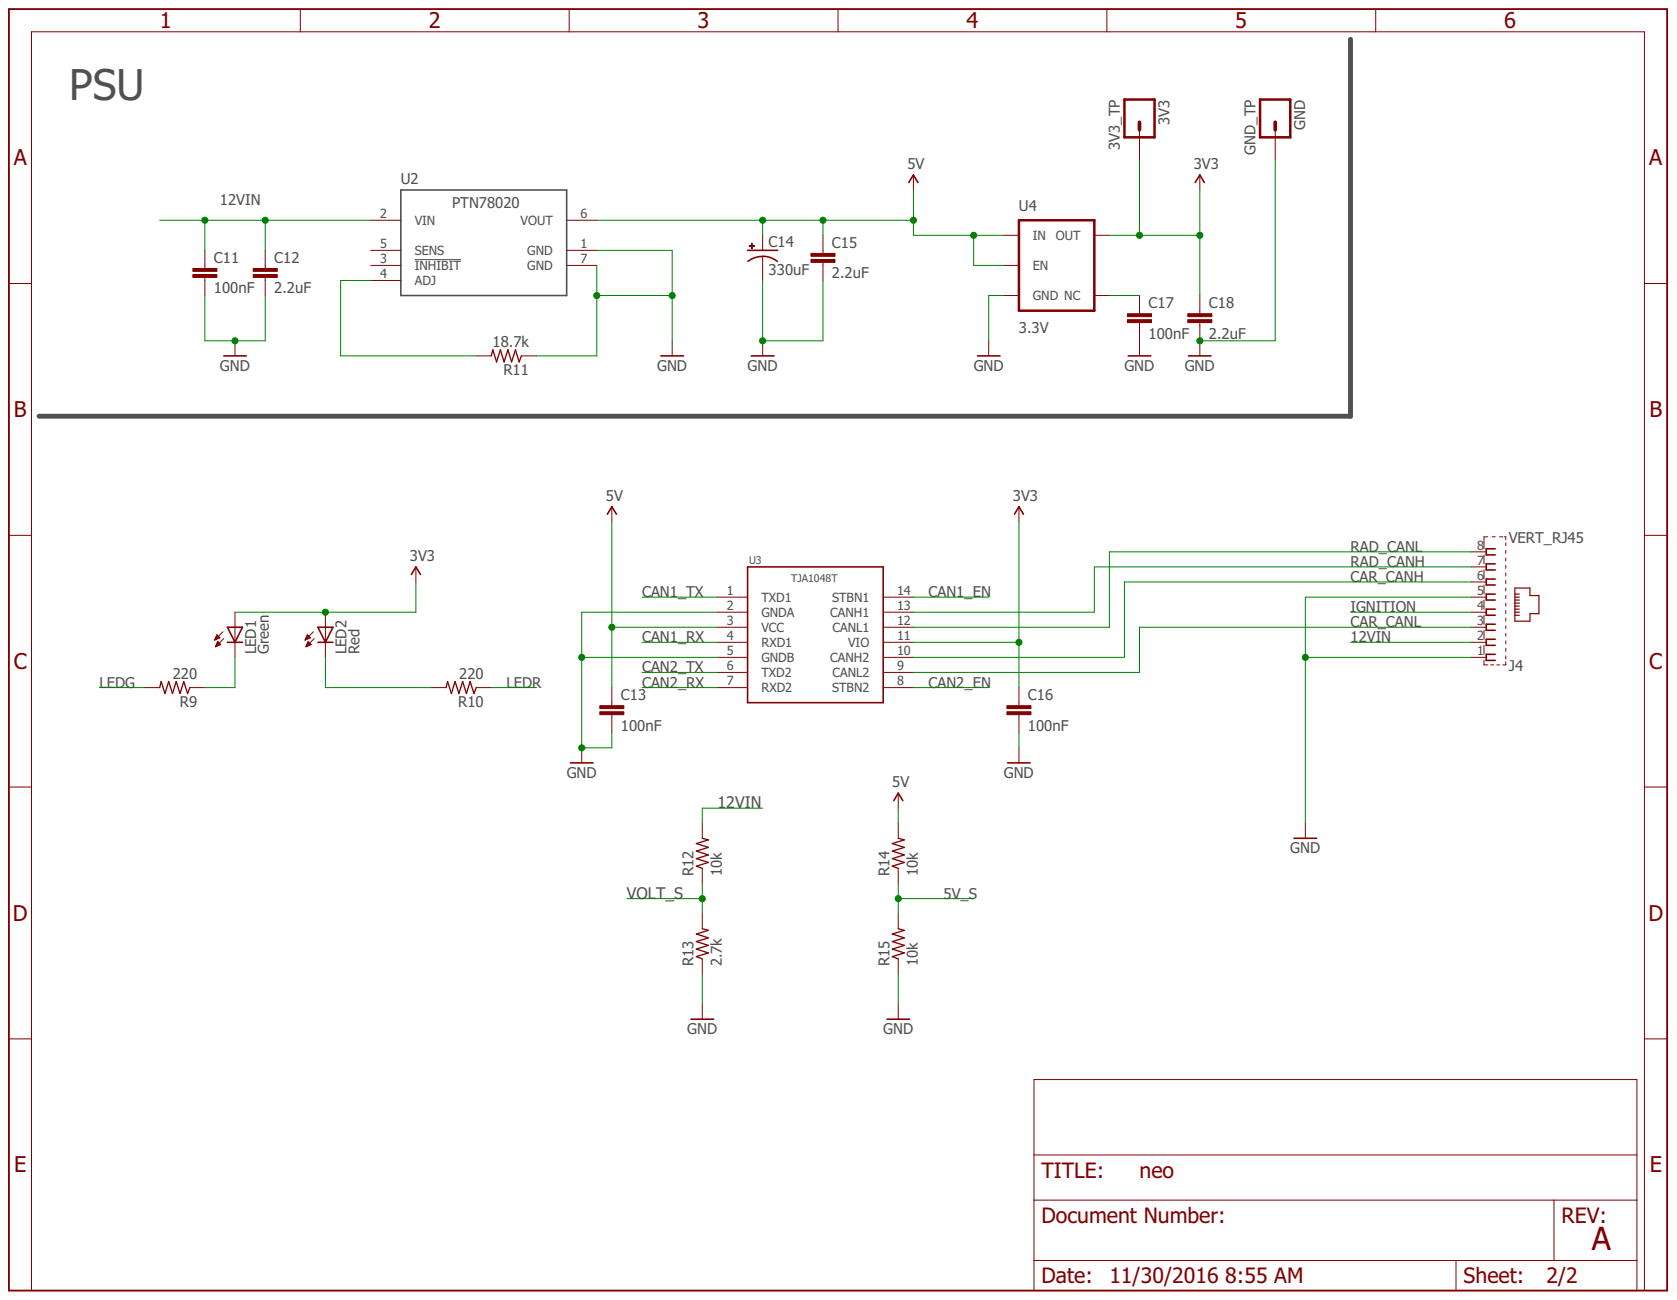
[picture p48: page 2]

Document Number: | REV: A

Date: 11/30/2016 8:55 AM | Sheet: 2/2

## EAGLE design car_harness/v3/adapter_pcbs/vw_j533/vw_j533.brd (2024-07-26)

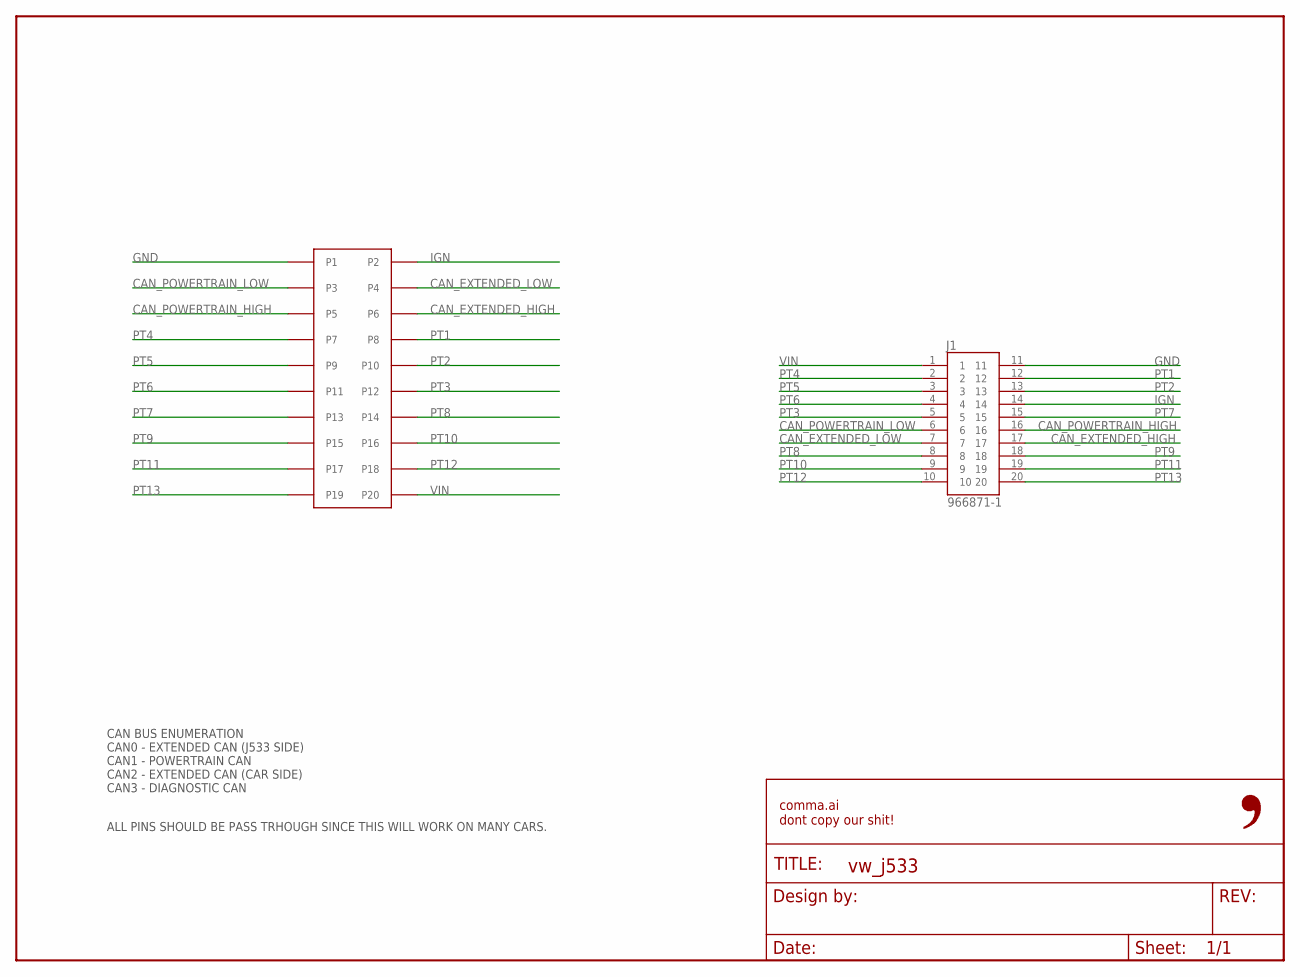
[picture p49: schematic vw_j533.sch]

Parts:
FRAME1: FRAME-LETTERNO_PACKAGE; DUMMY
J1: 966871-1; TE_966871-1
J2: 5018762040

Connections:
CAN_EXTENDED_HIGH: J1.17, J2.P6
CAN_EXTENDED_LOW: J1.7, J2.P4
CAN_POWERTRAIN_HIGH: J1.16, J2.P5
CAN_POWERTRAIN_LOW: J1.6, J2.P3
GND: J1.11, J2.P1
IGN: J1.14, J2.P2
PT1: J1.12, J2.P8
PT2: J1.13, J2.P10
PT3: J1.5, J2.P12
PT4: J1.2, J2.P7
PT5: J1.3, J2.P9
PT6: J1.4, J2.P11
PT7: J1.15, J2.P13
PT8: J1.8, J2.P14
PT9: J1.18, J2.P15
PT10: J1.9, J2.P16
PT11: J1.19, J2.P17
PT12: J1.10, J2.P18
PT13: J1.20, J2.P19
VIN: J1.1, J2.P20

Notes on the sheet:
CAN BUS ENUMERATION CAN0 - EXTENDED CAN (J533 SIDE) CAN1 - POWERTRAIN CAN CAN2 - EXTENDED CAN (CAR SIDE) CAN3 - DIAGNOSTIC CAN
ALL PINS SHOULD BE PASS TRHOUGH SINCE THIS WILL WORK ON MANY CARS.

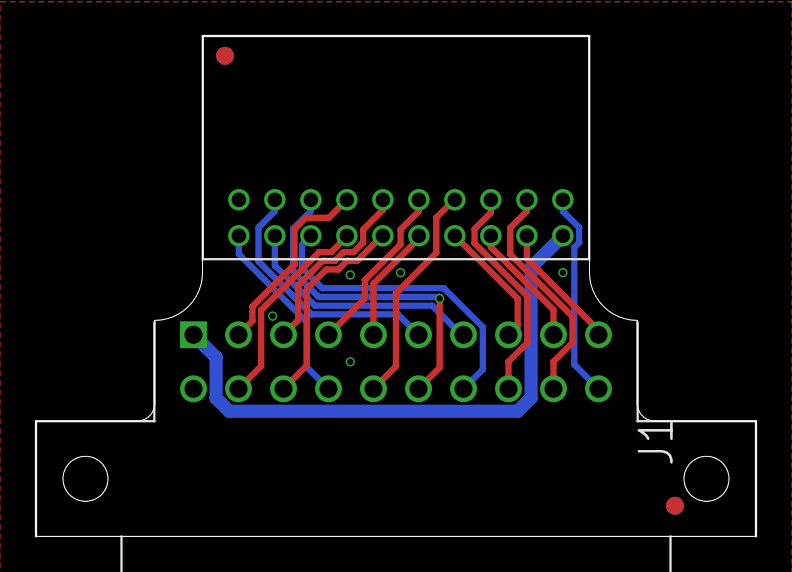
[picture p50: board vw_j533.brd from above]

Board: 2 copper layers, 40.0 x 27.8 mm, 6 parts (1 on the bottom side), 20 nets.

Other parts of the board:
U$1: LOGO
U$2, U$3: FIDUCIAL

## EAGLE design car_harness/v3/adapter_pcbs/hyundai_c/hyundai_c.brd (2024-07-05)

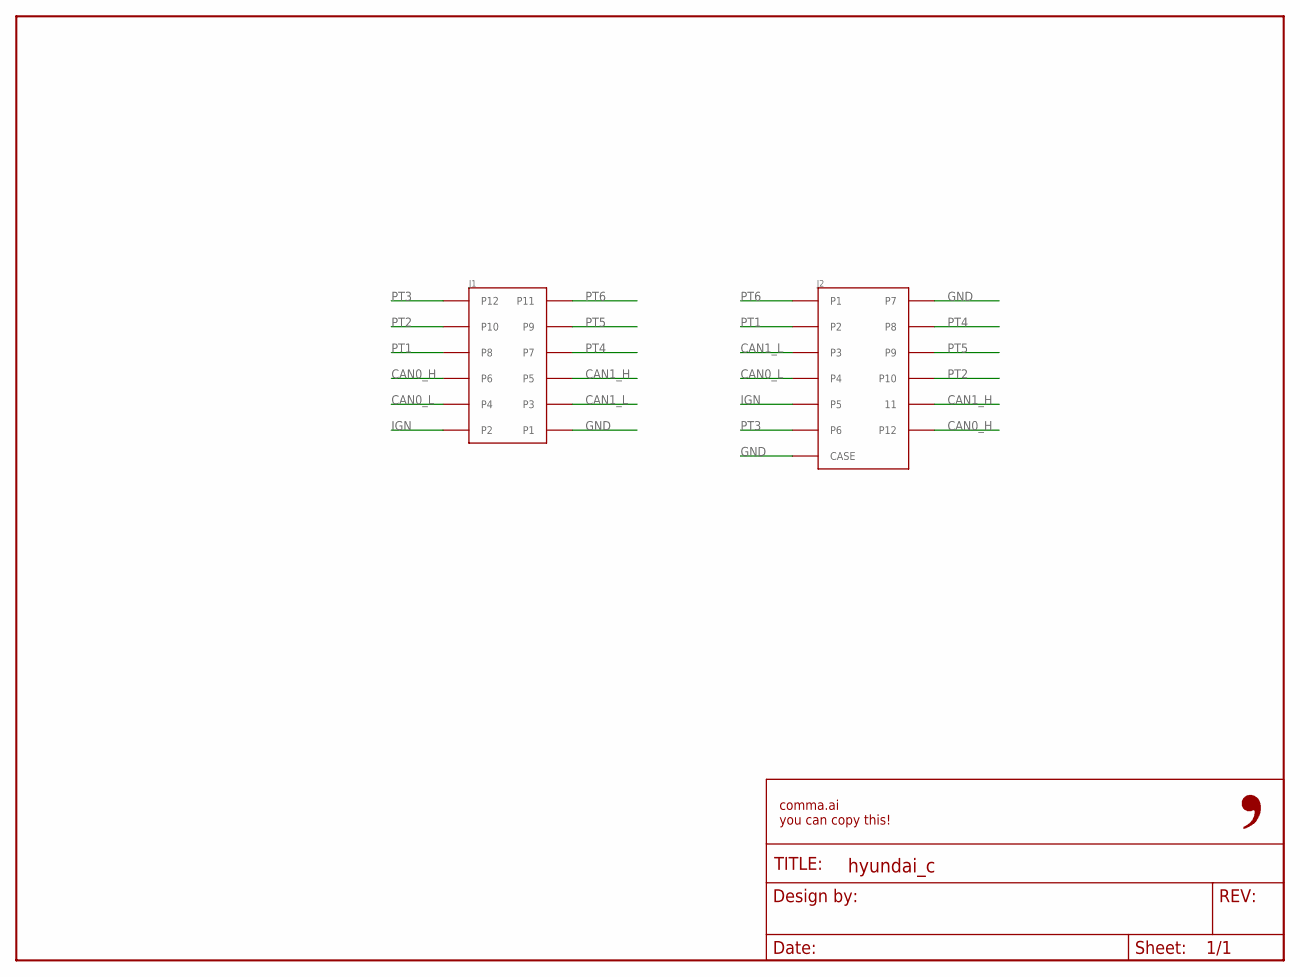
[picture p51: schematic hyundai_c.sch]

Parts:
FRAME1: FRAME-LETTER-OPENNO_PACKAGE; DUMMY
J1: 5018761240
J2: MG645845

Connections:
CAN0_H: J1.P6, J2.P12
CAN0_L: J1.P4, J2.P4
CAN1_H: J1.P5, J2.P11 (11)
CAN1_L: J1.P3, J2.P3
GND: J1.P1, J2.P7, J2.P$1 (CASE), J2.P$2 (CASE)
IGN: J1.P2, J2.P5
PT1: J1.P8, J2.P2
PT2: J1.P10, J2.P10
PT3: J1.P12, J2.P6
PT4: J1.P7, J2.P8
PT5: J1.P9, J2.P9
PT6: J1.P11, J2.P1

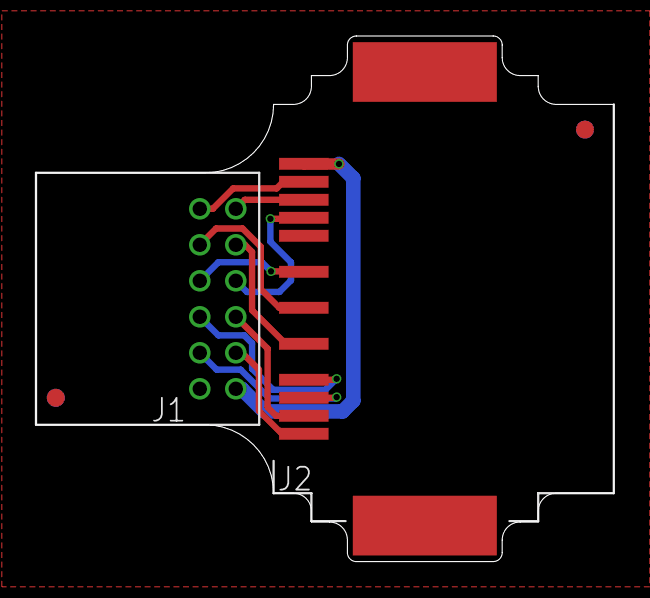
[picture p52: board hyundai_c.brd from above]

Board: 2 copper layers, 32.1 x 29.2 mm, 6 parts (1 on the bottom side), 12 nets.

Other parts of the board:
U$1: LOGO
U$2, U$3: FIDUCIAL

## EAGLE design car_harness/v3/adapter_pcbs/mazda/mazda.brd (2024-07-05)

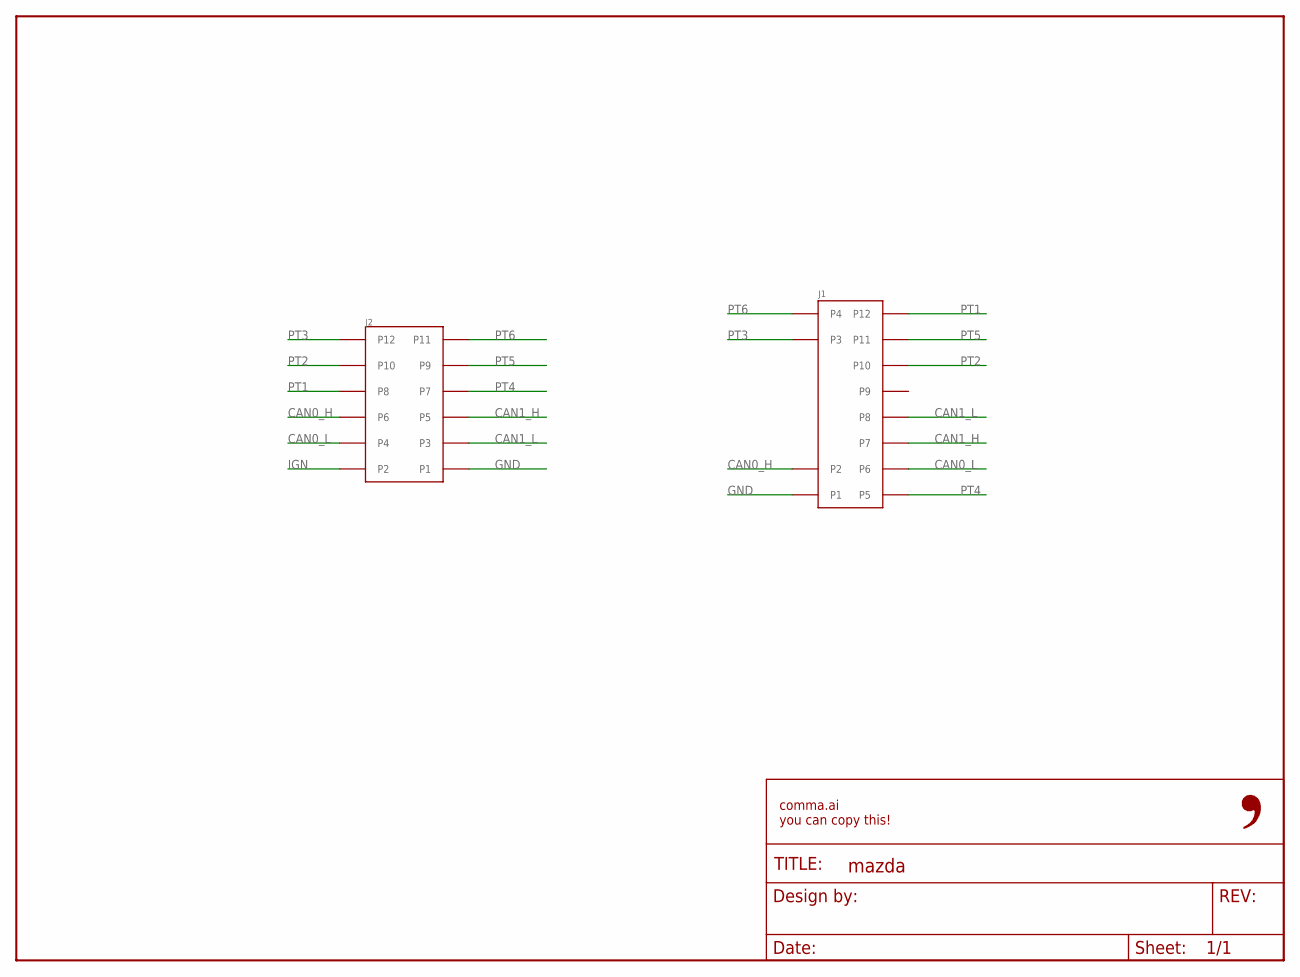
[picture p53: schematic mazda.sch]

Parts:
FRAME1: FRAME-LETTER-OPENNO_PACKAGE; DUMMY
J1: 0348260124
J2: 5018761240

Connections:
CAN0_H: J1.P2, J2.P6
CAN0_L: J1.P6, J2.P4
CAN1_H: J1.P7, J2.P5
CAN1_L: J1.P8, J2.P3
GND: J1.P1, J2.P1
IGN: J2.P2
PT1: J1.P12, J2.P8
PT2: J1.P10, J2.P10
PT3: J1.P3, J2.P12
PT4: J1.P5, J2.P7
PT5: J1.P11, J2.P9
PT6: J1.P4, J2.P11

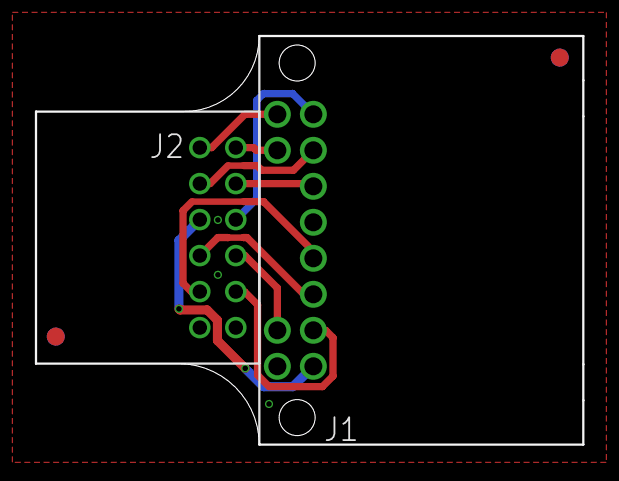
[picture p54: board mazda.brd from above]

Board: 2 copper layers, 30.4 x 22.7 mm, 6 parts (1 on the bottom side), 11 nets.

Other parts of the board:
U$1: LOGO
U$2, U$3: FIDUCIAL

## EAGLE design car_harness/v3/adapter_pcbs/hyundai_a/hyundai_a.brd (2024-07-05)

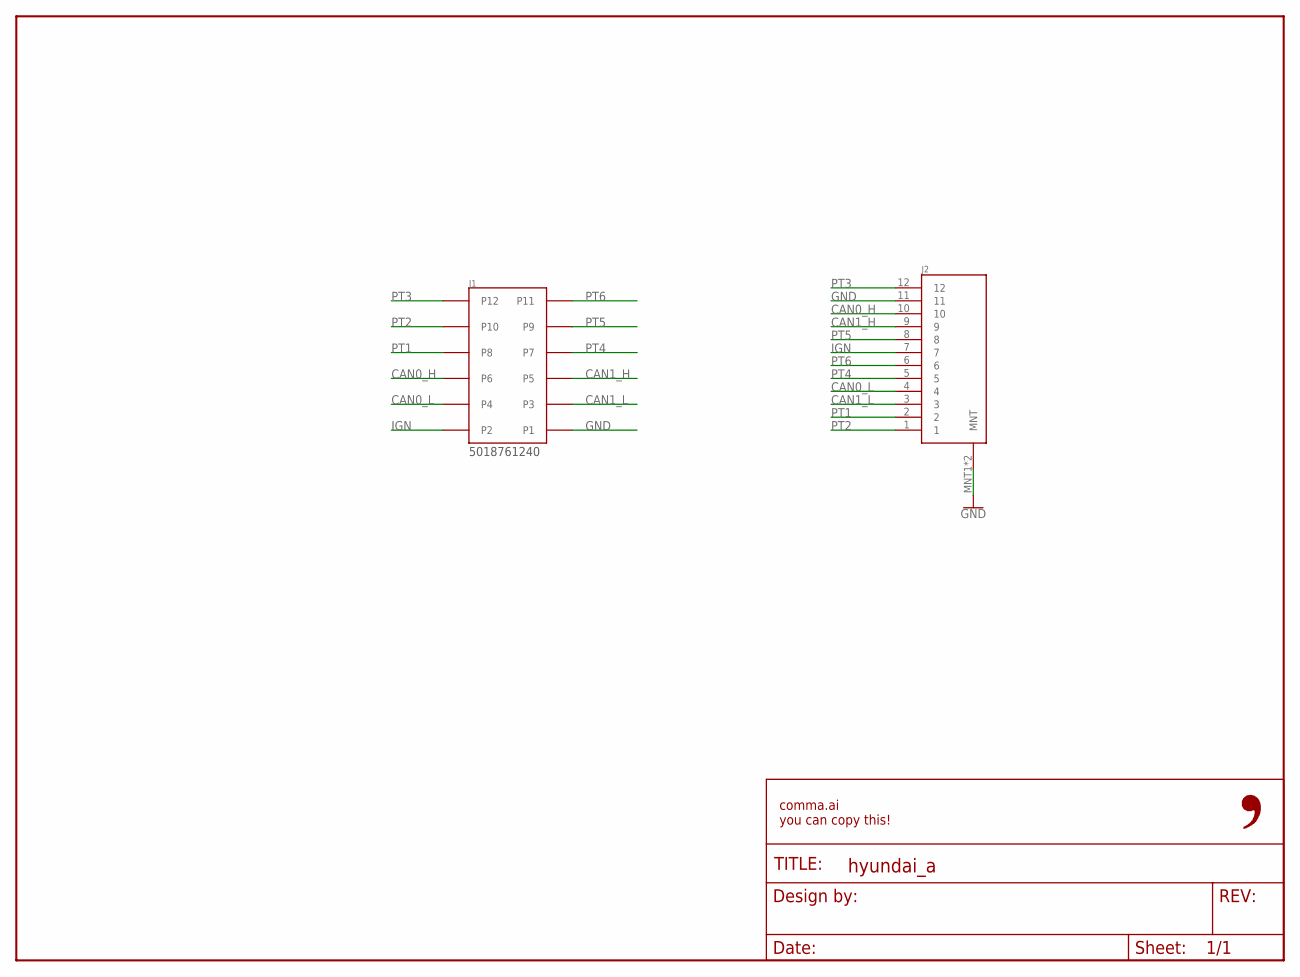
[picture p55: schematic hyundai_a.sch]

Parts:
FRAME1: FRAME-LETTER-OPENNO_PACKAGE; DUMMY
J1: 5018761240
J2: MG646151

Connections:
CAN0_H: J1.P6, J2.10
CAN0_L: J1.P4, J2.4
CAN1_H: J1.P5, J2.9
CAN1_L: J1.P3, J2.3
GND: J1.P1, J2.11, J2.MNT1 (MNT), J2.MNT2 (MNT)
IGN: J1.P2, J2.7
PT1: J1.P8, J2.2
PT2: J1.P10, J2.1
PT3: J1.P12, J2.12
PT4: J1.P7, J2.5
PT5: J1.P9, J2.8
PT6: J1.P11, J2.6

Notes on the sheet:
5018761240

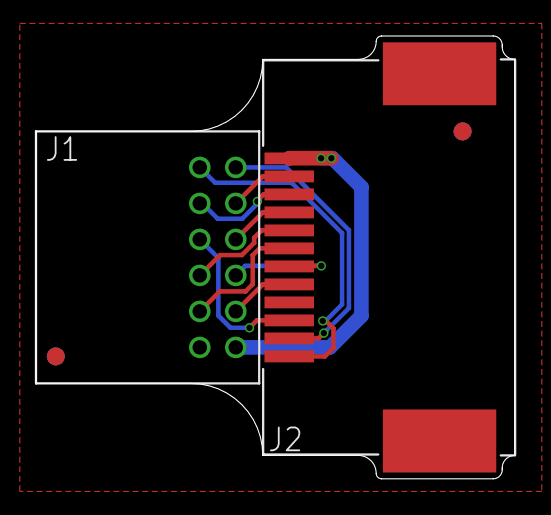
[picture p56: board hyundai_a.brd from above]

Board: 2 copper layers, 26.6 x 24.6 mm, 6 parts (1 on the bottom side), 12 nets.

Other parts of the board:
U$1: LOGO
U$2, U$3: FIDUCIAL

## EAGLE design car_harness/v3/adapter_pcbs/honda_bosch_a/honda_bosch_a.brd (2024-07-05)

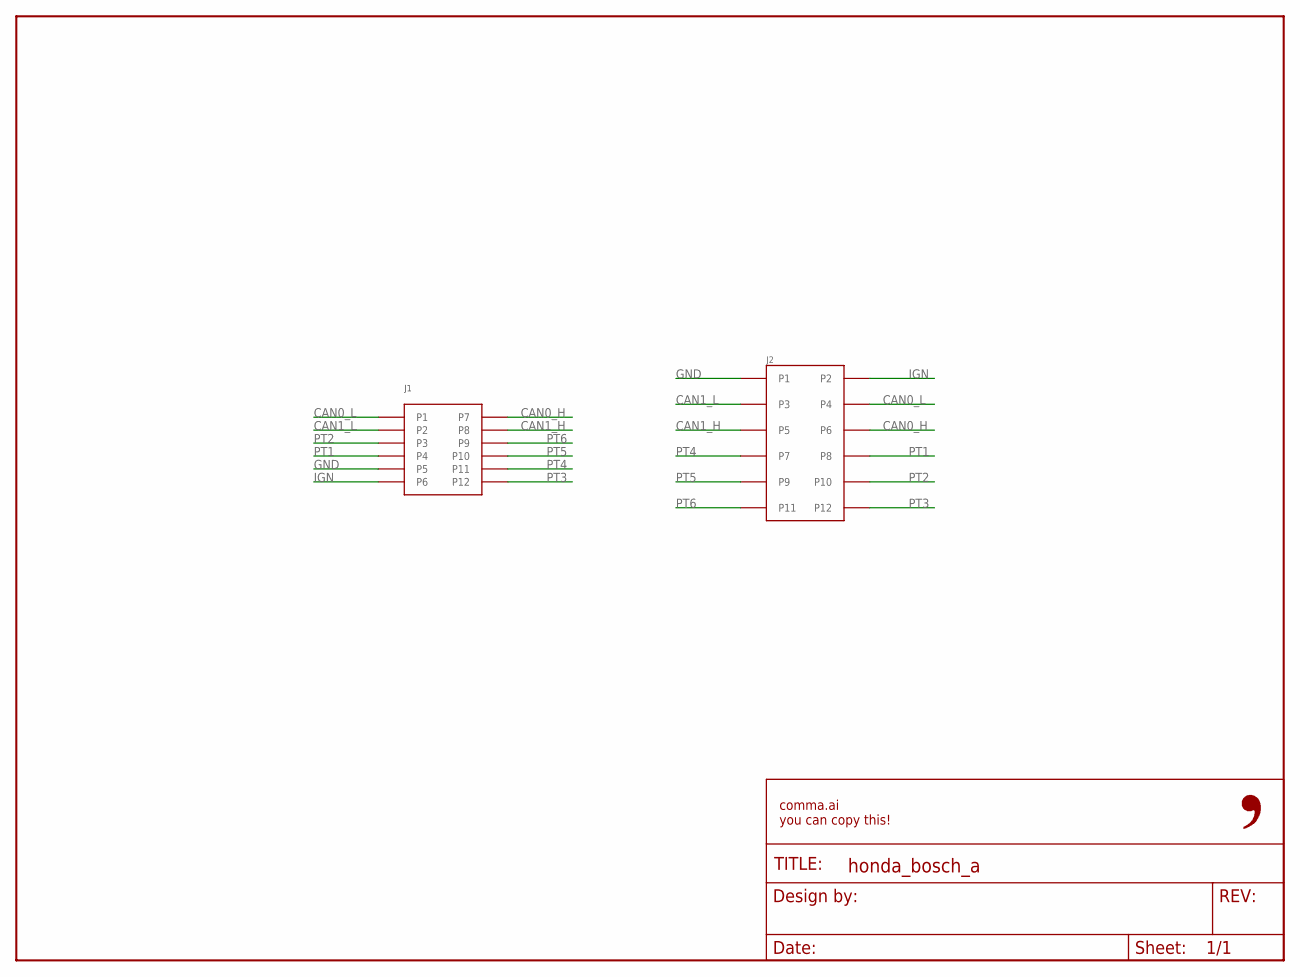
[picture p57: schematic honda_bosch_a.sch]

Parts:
FRAME1: FRAME-LETTER-OPENNO_PACKAGE; DUMMY
J1: MX34M12NF1
J2: 5018761240

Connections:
CAN0_H: J1.P7, J2.P6
CAN0_L: J1.P1, J2.P4
CAN1_H: J1.P8, J2.P5
CAN1_L: J1.P2, J2.P3
GND: J1.P5, J2.P1
IGN: J1.P6, J2.P2
PT1: J1.P4, J2.P8
PT2: J1.P3, J2.P10
PT3: J1.P12, J2.P12
PT4: J1.P11, J2.P7
PT5: J1.P10, J2.P9
PT6: J1.P9, J2.P11

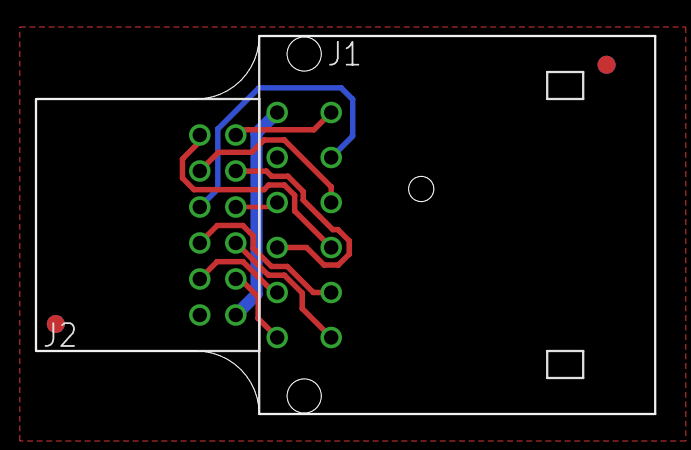
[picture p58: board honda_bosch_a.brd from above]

Board: 2 copper layers, 34.4 x 21.0 mm, 6 parts (1 on the bottom side), 12 nets.

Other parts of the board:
E$1: LOGO
U$2, U$3: FIDUCIAL

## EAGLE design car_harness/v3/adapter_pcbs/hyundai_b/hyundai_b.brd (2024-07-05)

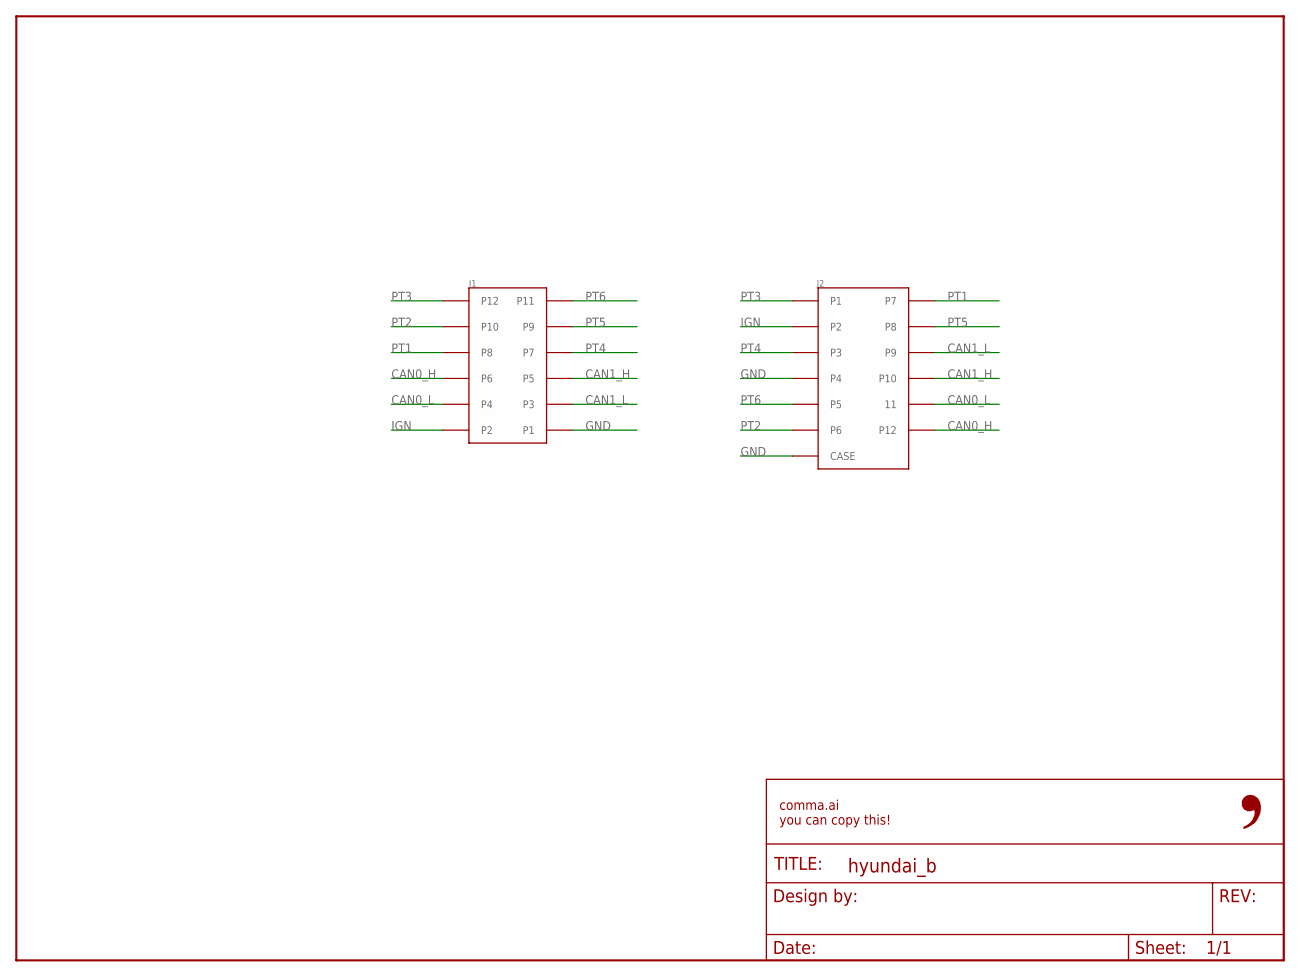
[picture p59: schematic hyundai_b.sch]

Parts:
FRAME1: FRAME-LETTER-OPENNO_PACKAGE; DUMMY
J1: 5018761240
J2: MG645845

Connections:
CAN0_H: J1.P6, J2.P12
CAN0_L: J1.P4, J2.P11 (11)
CAN1_H: J1.P5, J2.P10
CAN1_L: J1.P3, J2.P9
GND: J1.P1, J2.P4, J2.P$1 (CASE), J2.P$2 (CASE)
IGN: J1.P2, J2.P2
PT1: J1.P8, J2.P7
PT2: J1.P10, J2.P6
PT3: J1.P12, J2.P1
PT4: J1.P7, J2.P3
PT5: J1.P9, J2.P8
PT6: J1.P11, J2.P5

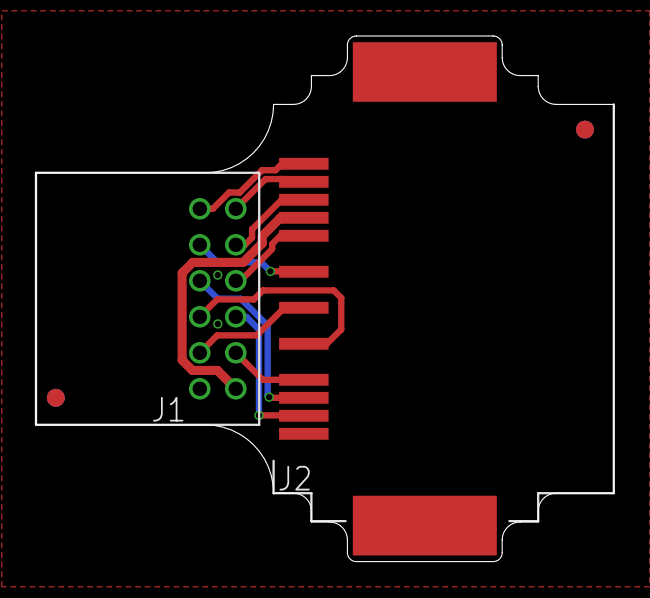
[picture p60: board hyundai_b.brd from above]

Board: 2 copper layers, 32.1 x 29.2 mm, 6 parts (1 on the bottom side), 12 nets.

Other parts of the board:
U$1: LOGO
U$2, U$3: FIDUCIAL

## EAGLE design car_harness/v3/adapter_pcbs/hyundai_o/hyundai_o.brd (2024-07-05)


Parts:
FRAME1: FRAME-LETTER-OPENNO_PACKAGE; DUMMY
J1: 5018761240
J2: MG646151

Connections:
CAN0_H: J1.P6, J2.4
CAN0_L: J1.P4, J2.11
CAN1_H: J1.P5, J2.3
CAN1_L: J1.P3, J2.10
GND: J1.P1, J2.12, J2.MNT1 (MNT), J2.MNT2 (MNT)
IGN: J1.P2, J2.7
PT1: J1.P8, J2.9
PT2: J1.P10, J2.8
PT3: J1.P12, J2.6
PT4: J1.P7, J2.2
PT5: J1.P9, J2.1
PT6: J1.P11, J2.5

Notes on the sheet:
5018761240


Board: 2 copper layers, 26.6 x 24.6 mm, 6 parts (1 on the bottom side), 12 nets.

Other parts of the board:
U$1: LOGO
U$2, U$3: FIDUCIAL

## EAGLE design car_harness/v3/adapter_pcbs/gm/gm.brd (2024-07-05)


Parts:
FRAME1: FRAME-LETTER-OPENNO_PACKAGE; DUMMY
J1: 0348260124
J2: 5018761240

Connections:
12VIN: J1.P3, J2.P11
CAN0_H: J1.P5, J1.P7, J2.P6
CAN0_L: J1.P6, J1.P8, J2.P4
CAN1_H: J2.P5
GND: J1.P1, J2.P1, J2.P3
IGN: J1.P9, J2.P2
PT1: J1.P2, J2.P8
PT2: J1.P4, J2.P10
PT3: J1.P10, J2.P12
PT4: J1.P11, J2.P7
PT5: J1.P12, J2.P9


Board: 2 copper layers, 30.4 x 22.7 mm, 6 parts (1 on the bottom side), 10 nets.

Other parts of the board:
U$1: LOGO
U$2, U$3: FIDUCIAL

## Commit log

2016-11-30 files and guide
    [bottom.stl, cover.stl, digikey.csv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]
2016-12-13 adding schematic pdf for github viewing
2016-12-29 macrofab placement bom & placement
2017-01-27 gopro adhesive compatible mount
    [goproslide.stl]
2017-02-22 updated digikey&macrofab BOM after USB out of stock, schematic cleanup
    [digikey.csv, neo.brd, neo.sch]
2017-06-02 push GIANTpanda w/ dual rj45 pinouts, many updates to comma.ai eagle library
    [GIANTpanda.brd, GIANTpanda.sch]
2017-06-04 add LED polarity placement to PCB, push digikey BOM
    [GIANTpanda.brd, GIANTpanda_bom.csv]
2017-06-28 silkscreen polarity indicator for optional LED was on the wrong side
    [GIANTpanda.brd]
2017-09-23 honda giraffe
    [BOM.csv, giraffe_20.brd, giraffe_20.sch]
2017-09-25 honda mirror to gopro slide adapter
    [honda_mirror_togopro.stl]
2017-10-09 remove unsupported giant panda
    [GIANTpanda.brd, GIANTpanda.sch, GIANTpanda_bom.csv]
2017-10-10 push honda giraffe case
    [case.stl]
2017-10-19 toyota giraffe push, update honda BOM with new screws
    [BOM.csv, giraffe12.brd, giraffe12.sch]
2017-11-20 missing Honda LKAS indicator, Honda LKAS2EPS now passed thru, pass thru all unused Toyota pins
    [giraffe20.brd, giraffe20.sch]
2017-11-20 toyota case stl
    [case.stl]
2017-12-19 update mirror to gopro adapter for production eon
    [honda_mirror_togopro.stl]
2018-01-26 toyota BOM was missing DC barrel connector
    [BOM.csv]
2018-02-07 eon mounts 22-30deg .stls
    [22deg.stl, 24deg.stl, 26deg.stl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]
2018-02-22 giraffe schematics as pdf
2018-03-01 antenna mount stl is open!
    [antenna_mount.stl]
2018-03-01 rotate for printing
    [antenna_mount.stl]
2018-03-29 comma pedal push
    [BOM.csv, comma.stl, interceptor.brd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]
2018-03-29 updated pedal BOM for out of stock cap
    [BOM.csv]
2018-04-06 Bosch Honda Giraffe
    [BOM.csv, case.stl, female_connector.stl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]
2018-04-24 push panda debug board
    [panda_debug.brd, panda_debug.sch]
2018-06-07 Odyssey/TLX board
    [giraffe20_flipped.brd, giraffe20_flipped.sch]
2018-06-07 Readme, BOM and Case
    [BOM.csv, case.stl]
2018-06-07 Changed folder name to nidec_inverted
    [BOM.csv, case.stl, giraffe20_flipped.brd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]
2018-08-07 Push Bosch Giraffe
    [BOM.csv, bosch_back.stl, bosch_female_connector.stl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]
2018-08-19 Update Bosch Case and BOM
    [BOM.csv, bosch_back.stl]
2018-08-20 grey panda antenna mount 28 degrees by @mhevery
    [antenna_mount_28deg.stl]
2018-09-11 Calbi Opensource day
    [BOM.csv, Hyundai_Giraffe.brd, Hyundai_Giraffe.sch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]
2018-09-13 Update sch and push case
    [Hyundai_Giraffe.brd, Hyundai_Giraffe.sch, Hyundai_Giraffe.stl]
2018-09-18 Update Hyundai Giraffe Case to give room to depress camera clip
    [Hyundai_Giraffe.stl]
2018-11-13 Fix BOM, flip J1 and J2 so parts match
    [BOM.csv]
2018-11-22 Push Inverted Nidec Giraffe
    [BOM.csv, case.stl, giraffe20_inverted.brd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]
2018-12-17 Create Toyota Giraffe Switch Settings Flowchart.pdf
2018-12-18 Flowchart in PNG, replace text in README.md
    Also added note that comma power should connect to car's OBD port.
2019-02-02 🦒 Giraffe for Chrysler, Jeep, and Dodge (#42)
    * giraffe for Chrysler Jeep and Dodge
    [giraffe-cjd-simple.brd, giraffe-cjd-simple.sch, giraffe-cjd.brd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]
2019-02-05 Push FCA Giraffe
    [BOM.csv, Giraffe_left.stl, Giraffe_right.stl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]
2019-02-05 fix links in FCA BOM (#44)
    What gauge header pins do you put in your crimps?
    [BOM.csv]
2019-02-05 add header pins for fca
    [BOM.csv]
2019-02-06 update resistor part with correct one
    [BOM.csv]
2019-02-15 Opensource GM Interface Board thanks to vtarasov
    [case.stl, connectors.stl, digikey.csv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]
2019-04-02 Move switch card images to individual giraffe folders (#49)
    Remove the switch card image from the main giraffe readme and add it to readme for each type of giraffe.
2019-04-02 Toyota Flowchart resistor update (#48)
    Update Toyota Giraffe Switch Settings Flowchart to note cars that require resistor.
2019-04-02 Revert "Toyota Flowchart resistor update (#48)" (#50)
    This reverts commit e825879428b67c9a77ed8ea770e7d3340e7e84cc.
2019-04-08 Fix GM Giraffe typos (#51)
    - Missing C18 in digikey.csv.
    - For DFU, BOOT needs to be pulled high, not low.
    [digikey.csv]
2019-04-23 Subaru Giraffe push
    [BOM.csv, PIP_left.stl, PIP_right.stl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]
2019-05-14 Toyota Giraffe: Add resistor
    [BOM.csv, giraffe12.brd, giraffe12.sch]
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2019-08-09 grey panda: flat antenna mount
    [flat_antenna_mount.stl]
2019-10-10 car harness: opensource pin outs and block diagrams
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2019-12-04 Car Harness: Update for additional PT wires for Lexus
2020-01-21 Updated OBDII-C Pinout
    A more user friendly visual of OBDII-C connector configuration.
2020-01-23 comma2: STL for mount
    [comma2_mount.stl]
2020-02-01 EON: New mount adapter for big mounts
    [mount_adapter.stl]
2020-04-24 comma2 : push new mount
    [comma2_injection_molded_mount.stl]
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2020-11-21 Comma Key: Push Key
    [BOM.csv, key.brd, key.sch]
2021-10-15 STL of printable comma 3 mount
    [comma3_mount.stl]
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2021-12-11 push harness adapter boards
    [Bosch.brd, Bosch.sch, Kona.brd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]
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2022-05-08 Body: add C3 stand STL
    [C3_stand.stl]
2022-06-17 Kia EV6 Harness and board
    [EV6.brd, EV6.sch]
2022-07-08 Car Harness: Update Bosch harnesses
    [Bosch_A.brd, Bosch_A.sch, Bosch_B.brd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]
2022-09-27 Car harness: Push GM/Bolt harness
    [bolt.brd, bolt.sch]
2022-09-27 Car harness: Ford Q3
    [ford_q3.brd, ford_q3.sch]
2022-11-17 Car Harness: push 3D printed connectors
    [Ford_Q4_connector.stl, Ford_Q4_connector_cap.stl, RAM_connector.stl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]
2023-02-09 Push 8 degree C3 mount
    [8_degree_c3_mount.stl]
2023-07-31 3X: Mounts
    [3X_mount.stl, 3X_mount_8deg.stl]
2023-12-14 body: add hat and wheeled stand
    [universal_C3_C3X_hat.stl, universal_C3_C3X_hat_frame.stl, wheeled_stand.stl]
2024-07-05 opensource harness v3 schematics
    [Bosch_A.brd, Bosch_A.sch, Bosch_B.brd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]
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2024-07-26 update j533
    [vw_j533.brd, vw_j533.sch]
2024-07-26 update Ford Q4 and RAM connector part numbers
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
